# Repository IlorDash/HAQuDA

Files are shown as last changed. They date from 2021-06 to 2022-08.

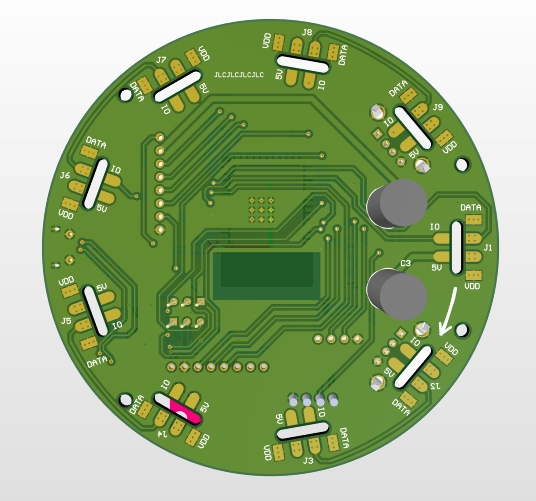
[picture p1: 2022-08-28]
Scheme/HAQuDA_Schematic/HAQuDA_Schematic_Bottom_Photo.jpg

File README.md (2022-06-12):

# HAQuDA
Home Air Quality Display And so on

Repository for project HAQuDA - table lamp that displays data of environmental parameters: air quality, temperature and humidity, by color of LEDs

Software is developed with VisualGDB

Article about (ru)
https://habr.com/ru/post/647117/

Assembly

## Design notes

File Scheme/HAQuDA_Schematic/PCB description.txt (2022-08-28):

Rounded rectangle slots (2.2 x 10.2 mm) around the board circle must be NON-PLATED. I placed in archive photos of each layers, how PCB must looks like

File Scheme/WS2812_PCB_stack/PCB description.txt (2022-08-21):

PCB is a panel of 6 PCBs (15mm x 96mm) similar design. I'd like it to be V-cut between each PCB. Single PCB outline is presented in layer - Mechanical 1. In each single PCB lengths between traces to outline are equal to 0.4mm, that fit to V-cut clearance.

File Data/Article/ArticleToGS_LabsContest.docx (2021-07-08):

# ОКВоДи: Отображатель Качества Воздуха Дома и так далее

# Оглавление

1. Сокращения
2. Описание
3. Актуальность
4. Устройство ОКВоДи
5. Основные функции
6. Прототип
7. Архитектура устройства
8. Технические характеристики

# Сокращения

PM 1.0, 2.5, 10 - particulate matter (взвешенные твердые микрочастицы размером <1 мкм, <2.5 мкм и <10 мкм соответственно. Примеры: пыль, вирусы и пыльца)
TVOC - total volatile organic compounds (общее количество летучих органических соединений. Примеры: сигаретный дым, бытовые и строительные аэрозоли, краски)
ppb - parts per billion (миллиардная доля, 1 ppb = 1 мм³/м³ - объемная доля или 1 ppb = 1 мкг/кг – массовая доля)
ppm – parts per million (миллионная доля, 1% = 10 000 ppm)
ОКВоДи – Отображатель Качества Воздуха Дома и так далее
HAQuDA – Home Air Quality Display And so on

# Описание

ОКВоДи – это настольная лампа, которая отображает данные о параметрах окружающей среды: качестве воздуха, температуре и влажности, при помощи цвета свечения. Если параметр в норме, то он зеленый, а если завышен или занижен, то красный или синий соответственно. У лампы есть несколько режимов отображения: стандартный, мульти, ночной, режим светильника.

# Актуальность

Основная идея устройства заключается в простоте передачи информации о состоянии дома человеку. Существующие модели датчиков качества воздуха передают информацию понятную специалистам, но специфичную для простых пользователей, например единица измерения CO2 – PPM, а количество летучей органики (формальдегиды, ацетон, этанол и т.д.) измеряется в микрограммах на кубический метр. ОКВоДи позволяет моментально и понятно отображать информацию о качестве воздуха, за счет ее отображения цветом: от зеленого – качество воздуха хорошее, до красного - когда уже пора проветрить помещения. В этом устройстве заложен принцип “преаттентивности” (от англ. pre-attention) - показывать тот объем информации, который необходим для принятия решения, что позволит человеку быстрее обрабатывать информации, не фокусируя на ней внимание. Этот принцип уже протестирован на устройстве, которое сделал мой брат: ОПЭДИ (https://habr.com/ru/post/523988/) и оно получило одобрение сообщества.

# Устройство ОКВоДи

Отображатель качества воздуха дома и так далее представляет собой лампу цилиндрической формы (90x130мм) состоящую из двух частей: матовая полупрозрачная белая верхняя часть и основание из непрозрачного пластика. Внутри верхней части на цилиндре закреплены адресные светодиоды WS2812B, в количестве 12x9 штук. Труба вставляется в плату и закрепляется в ней. На плате расположены ESP-32 mini и следующие датчики: датчик влажности и температуры – DHT-11 (https://www.mouser.com/datasheet/2/758/DHT11-Technical-Data-Sheet-Translated-Version-1143054.pdf), датчик летучих органических соединений и датчик угарного газа – CCS811 (https://cdn.sparkfun.com/assets/learn_tutorials/1/4/3/CCS811_Datasheet-DS000459.pdf), датчик озона - ZE25-O3 (https://www.winsen-sensor.com/sensors/o3-gas-sensor/ze25-o3.html). Под платой располагается датчик взвешенных частиц - ZH03B (https://www.winsen-sensor.com/sensors/dust-sensor/zh3b.html). Отладочный комплект Silicon Labs будет подключаться снаружи по протоколу UART. Для изменения яркости лампы в зависимости от яркости окружающего света, установлены датчики освещения. В верхней крышке расположены сенсорные кнопки, чтобы отслеживать касания и менять режим отображения, и датчик расстояния, для ручного управления яркостью. Также на плате располагается два USB-A выхода для зарядки устройств и один USB-Micro вход питания. В комплектации к лампе идет адаптер питания 5В 2А с выходом на USB-A и кабель USB-A – USB-Micro. Для работы требуется подключение в сеть электропитания, по этой причине в сети ZigBee ОКВоДи будет выступать в роли координатора. Режим работы у лампы только рабочий.

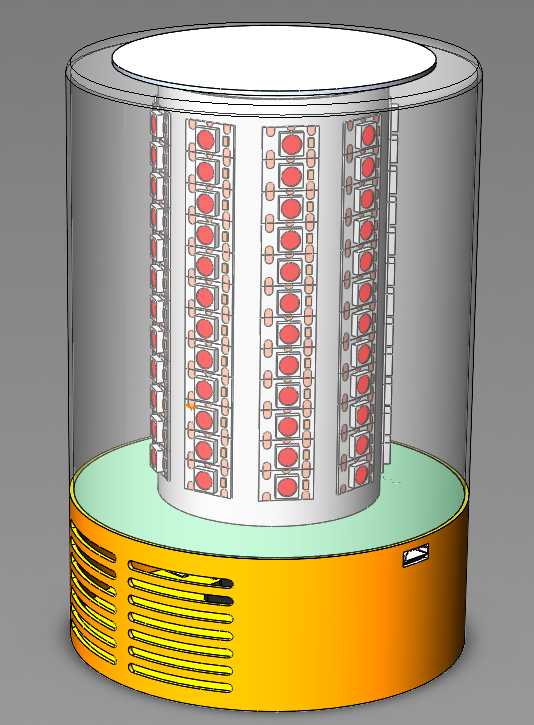
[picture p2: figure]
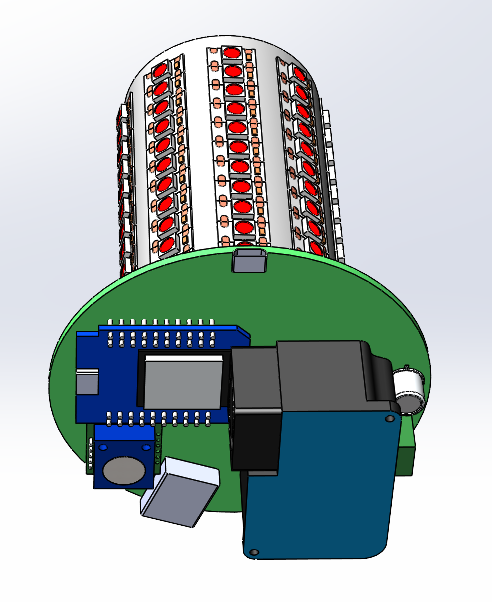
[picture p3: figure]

Расположение компонентов

Модель лампы

# Основные функции

ОКВоДи умеет отображать следующие параметры микроклимата дома:

- Летучие органические соединения (TVOC) – измеряется в частицах на миллиард [ppb]
- Количество озона (O3) – измеряется в частицах на миллиард [ppb]
- Твердые частицы PM1.0, PM2.5, PM10 (Dust) – измеряется в микрограммах на метр кубический [мкг/м3]
- Углекислый газ (CO2) - измеряется в частицах на миллион [ppm]
- Температура – измеряется в градусах Цельсия [°C]
- Влажность – измеряется в процентах [%]
- Общее качество воздуха (TotalAirQuality) – рассчитывается на основе всех предыдущих показателей

Выбор именно этих показателей качества воздуха связан с тем, что они оказывают основное долговременное воздействие на человека. Исследования, доказывающие влияние качества воздуха на состояние человека и международные нормы количества этих показателей в помещениях:

1. Ioannis Manisalidis, Elisavet Stavropoulou, Agathangelos Stavropoulos and Eugenia Bezirtzoglou Environmental and Health Impacts of Air Pollution: A Review / Front. Public Health, 20 February 2020 - https://www.frontiersin.org/articles/10.3389/fpubh.2020.00014/full
2. Vinh Van Tran, Duckshin Park, and Young-Chul Lee Indoor Air Pollution, Related Human Diseases, and Recent Trends in the Control and Improvement of Indoor Air Quality / Int J Environ Res Public Health. 2020 Apr; 17(8) -https://www.ncbi.nlm.nih.gov/pmc/articles/PMC7215772/
3. Мансуров Р.Ш. Гурин М.А. Рубель Е.В. Влияние концентрации углекислого газа на организм человека / Universum: технические науки 2017 № 8 (41) - https://7universum.com/ru/tech/archive/item/5045
4. Губернский Ю.Д. Калинина Н.В. Гапонова Е.Б. Банин И.М. Обоснование допустимого уровня содержания диоксида углерода в воздухе помещений жилых и общественных зданий / ГИГИЕНА И САНИТАРИЯ Том 93, № 6 (2014) https://elibrary.ru/item.asp?id=22804038
5. Occupational Safety and Health Administration OSHA and Ozone - https://ozonesolutions.com/blog/osha-and-ozone/

Режимы отображения:

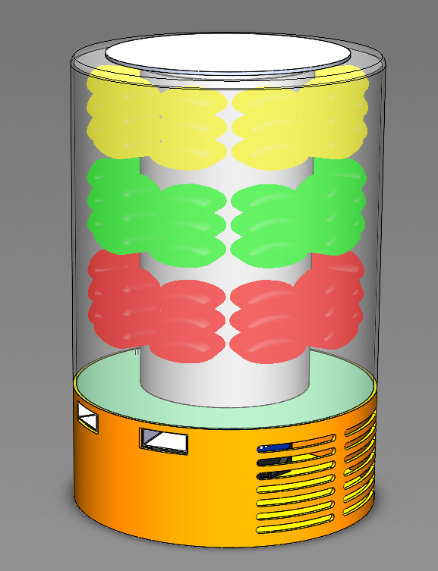
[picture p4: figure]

- Основной (Standard-mode) – все светодиоды задействованы для одного конкретного параметра
- Мульти-режим (Multi-mode) – светодиоды делятся на три секции и отображают три параметра, выбранные пользователем
- Ночной (Night-mode) – три вертикальные линии светодиодов выделяются под отображение одного параметра, заданного пользователем, остальные выполняют роль подсветки-ночника и отображают время. Пользователь вводит временной диапазон, например от времени засыпания, до будильника, по умолчанию установлен с 21.00 до 09.00. Каждый час загорается следующий светодиод подсветки, таким образом яркость ночника увеличивается с наступлением утра. Отображение времени тоже преаттентивно: по уровню заполнения подсветки можно примерно определить оставшееся время для сна. В итоге получается progress bar времени вашего сна.

Пример мульти-режима, выключенные светодиоды не отображены

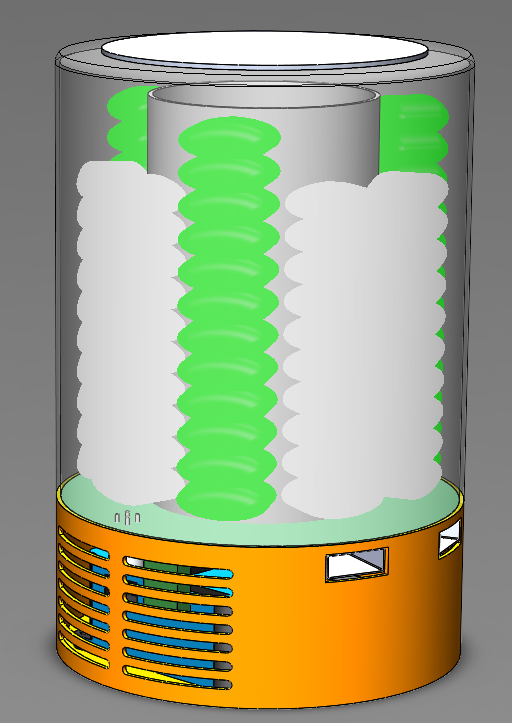
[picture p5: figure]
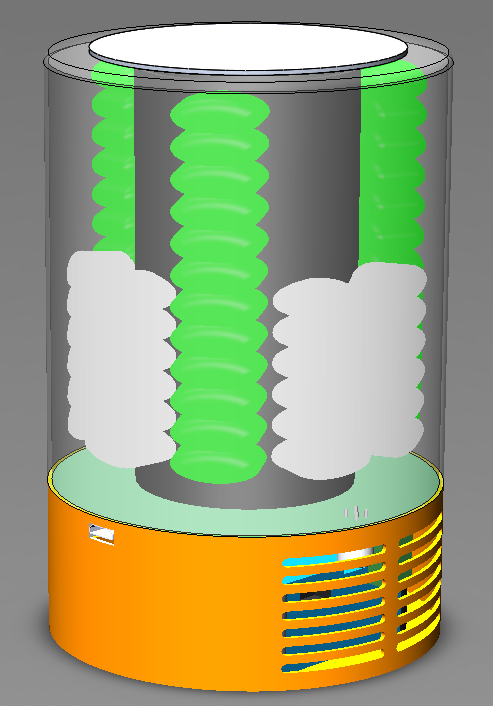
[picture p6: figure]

Пример ночного режима с установленным по умолчанию диапазоном времени. Зеленые – полосы отображения, например качества воздуха, белые - подсветка. Первая картинка соответствует 3 часам ночи, вторая – 7 часам утра

Так как это лампа, у нее есть одноцветная подсветка любым цветом (Lamp-mode), и несколько эффектов (Effect-mode): горящее пламя, огоньки, радуга. Пользователь может управлять автоматической регулировкой яркости, она происходит благодаря датчикам освещенности. Также менять яркость можно с помощью дальномера: поднесите руку над ОКВоДи и поднимая руку вы будете увеличивать яркость и наоборот. Для полного выключения освещения лампы достаточно хлопнуть по верхней крышке, в которой установлен сенсорный датчик.

Для удаленного управление лампой на модуле ESP-32 будет развернут веб-сервер, который позволит менять режимы отображения параметров, включать одноцветную подсветку и эффекты. На веб-сервере будут отображаться текущие показатели микроклимата дома, графики показателей за несколько дней.

ОКВоДи будет интегрирована с Яндекс Алисой для голосового управления. С помощью навыка “Домовенок Кузя” Алиса будет отправлять HTTP запросы на веб-сервер ESP-32 и, например, включать ночной режим или выключать лампу. Выбор Алисы обусловлен ее популярностью, поддержкой русского языка и простотой ее навыка. Так же для поддержки iOS устройств будет реализована интеграция с Apple HomeKit посредством ESP HomeKit SDK.

В сопряжении с другими устройствами умного дома, ОКВоДи сможет работать и как информационный модуль, и как управляющий. ОКВоДи будет получать информацию от других датчиков и так же отображать ее цветом светодиодов. Например, датчик энергопотребления будет сообщать свои данные лампе, а та в свою очередь будет отображать их, для контроля за энергопотреблением в реальном времени. Это можно будет применить и в сценариях, подобным, "Выход из дома", то есть показать, что основная часть электроприборов отключена. Другой вариант - отображать усредненные параметры качества воздуха с нескольких датчиков, расположенных в доме. В случае ухудшения качества воздуха, например увеличении концентрации CO2, ОКВоДи сможет подать команду на открытие окна или включения бризера. Общение между модулями будет реализовано с помощью Wi-Fi или ZigBee, в зависимости от внешнего устройства. Для отображения данных других датчиков необходимо будет добавить соответствующее значение атрибуту Description (0x001C) кластеров Display param 1-3.

# Прототип

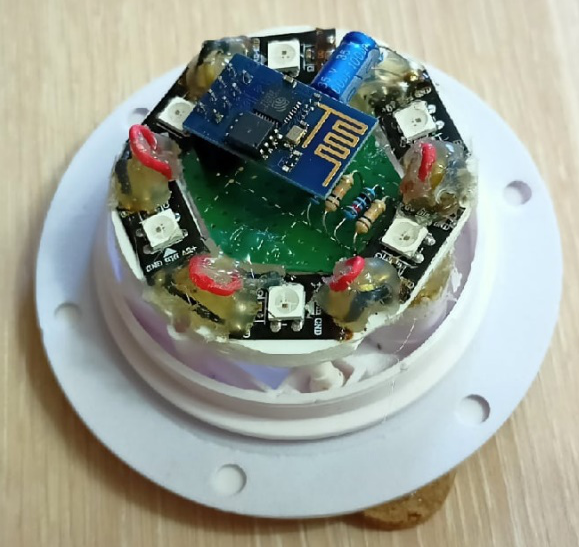
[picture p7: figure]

Уже имеется прототип ОКВоДи – умная лампа Ambient Orb, выполненная на WiFi модуле ESP-8266 и адресных светодиодах. Она умеет отображать температуру или влажность в помещении цветом светодиодов.

Плата Ambient Orb

Однако из-за небольшого количества светодиодов, на лампе нельзя реализовать много режимов отображения. Также отображение температуры в рамках одной комнаты оказалось не столь необходимым, так как человек сразу ощущает, что в комнате некомфортная температура, но с качеством воздуха все обстоит немного иначе, комнатный воздух – тихий убийца: вы не сразу почувствуете, что он ухудшился, однако последствия этого могут быть очень неприятными, от головной боли до инсульта, сердечно-сосудистых заболеваний, и даже рака легких. Поэтому я решил доработать AmbientOrb, сделать его более функциональным, полезным и совместить с другими устройствами умного дома. Так и родилась идея ОКВоДи!

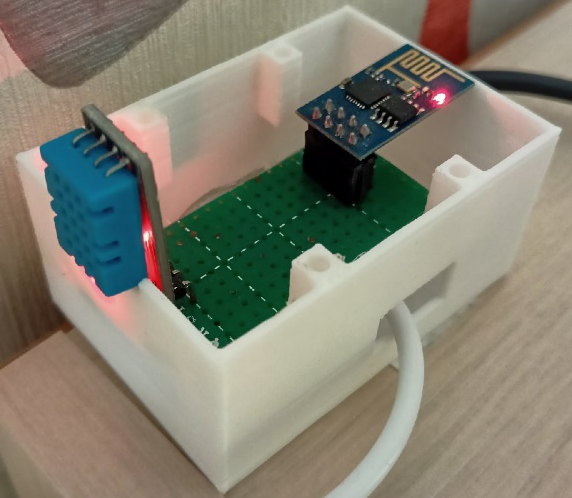
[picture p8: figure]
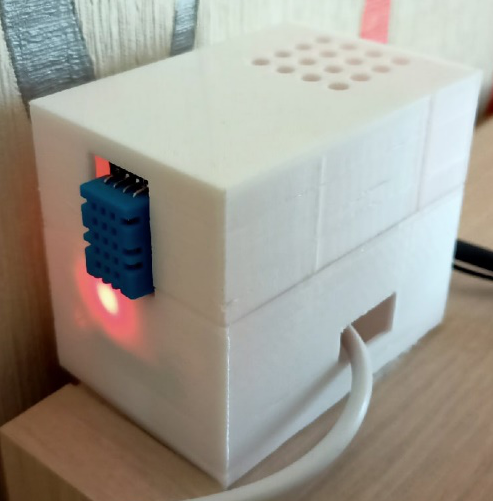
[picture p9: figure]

Для измерения влажности и температуры собран внешний датчик на DHT-11 и ESP-8266, который отправляет данные на Ambient Orb для их последующего отображения.

Датчик температуры и его плата

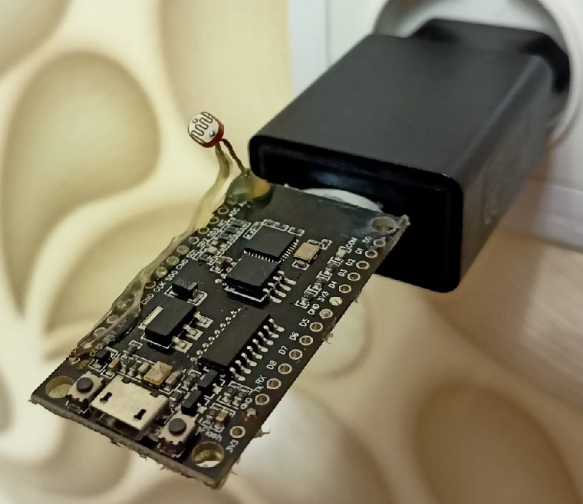
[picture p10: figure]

Яркость Ambient Orb может менять автоматически, в зависимости от внешнего освещения с помощью датчика света на фоторезисторе и платформе Node MCU.

Датчик света

Все эти устройства подключены к домашней сети Wi-Fi, датчики отправляют свои данные на Ambient Orb через HTTP запросы. Питаются все устройства от 5В и у всех есть для этого USB-A выходы. На Ambient Orb развернут веб-сервер, на котором можно настроить параметры лампы. Для голосового управления я подключил к Ambient Orb голосового помощника от Google через сервис IFTTT, который отправлял HTTP запросы на веб сервер. Видео демонстрацию работы Ambient Orb доступно на Яндекс Диске https://disk.yandex.ru/i/SMD_wlGtvY4n-g.

# Архитектура устройства

Endpoint 1. HAQuDa-general
Cluster | Description
Basic cluster 0x0000 (0) | Attributes ID | Name | Default value
| 0x0000 (0) | ZCL version | 2
| 0x0003 (3) | HW version | 0x01
| 0x0004 (4) | Manufacture name | IlorDash
| 0x0005 (5) | Model identifier | HAQuDA
| 0x0006 (6) | Date Code | 2021.6.09
| 0x0007 (7) | Power source | 0x04
Identify cluster 0x0003 (3) | Attributes ID | Name | Default value
| 0x0000 (0) | Identify Time | 0x0000
On/Off cluster 0x0006 (6) | Attributes ID | Name | Default value
| 0x0000 (0) | OnOff | 1
Mode 0xfc01 (64512) (CUSTOM) | Attributes ID | Name | Default value
| 0x001C | Description | Standard (Other modes: Multi, Night, Lamp, Effects)

Endpoint 2. Standard-mode
Cluster | Description
Basic cluster 0x0000 (0) | Attributes ID | Name | Default value
| 0x0000 (0) | ZCL version | 2
| 0x0003 (3) | HW version | 0x01
| 0x0004 (4) | Manufacture name | IlorDash
| 0x0005 (5) | Model identifier | HAQuDA
| 0x0006 (6) | Date Code | 2021.6.09
| 0x0007 (7) | Power source | 0x04
Identify cluster 0x0003 (3) | Attributes ID | Name | Default value
| 0x0000 (0) | Identify Time | 0x0000
Level Control 0x0008 (8) | Attributes ID | Name | Default value
| 0x0000 | CurrentLevel | -
| 0x0001 | RemainingTime | 0x0000
| 0x0010 | OnOffTransitionTime | 0x0000
| 0x0011 | OnLevel | 0xff
Display param 1 0xfc01 (64513) (CUSTOM) | Attributes ID | Name | Default value
| 0x001C | Description | TotalAirQuality (Other parameters to display: TVOC, O3, Dust, CO2, Temp, Humid)

Endpoint 3. Multi-mode
Cluster | Description
Basic cluster 0x0000 (0) | Attributes ID | Name | Default value
| 0x0000 (0) | ZCL version | 2
| 0x0003 (3) | HW version | 0x01
| 0x0004 (4) | Manufacture name | IlorDash
| 0x0005 (5) | Model identifier | HAQuDA
| 0x0006 (6) | Date Code | 2021.6.09
| 0x0007 (7) | Power source | 0x04
Identify cluster 0x0003 (3) | Attributes ID | Name | Default value
| 0x0000 (0) | Identify Time | 0x0000
Level Control 0x0008 (8) | Attributes ID | Name | Default value
| 0x0000 | CurrentLevel | -
| 0x0001 | RemainingTime | 0x0000
| 0x0010 | OnOffTransitionTime | 0x0000
| 0x0011 | OnLevel | 0xff
Display param 1 0xfc01 (64513) (CUSTOM) | Attributes ID | Name | Default value
| 0x001C | Description | TotalAirQuality (Other parameters to display: TVOC, O3, Dust, CO2, Temp, Humid)
Display param 2 0xfc02 (64514) (CUSTOM) | Attributes ID | Name | Default value
| 0x001C | Description | Temp (Other parameters to display: TVOC, O3, Dust, CO2, TotalAirQuality, Humid)
Display param 3 0xfc03 (64515) (CUSTOM) | Attributes ID | Name | Default value
| 0x001C | Description | Humid (Other parameters to display: TVOC, O3, Dust, CO2, TotalAirQuality, Temp)

Endpoint 4. Night-mode
Cluster | Description
Basic cluster 0x0000 (0) | Attributes ID | Name | Default value
| 0x0000 (0) | ZCL version | 2
| 0x0003 (3) | HW version | 0x01
| 0x0004 (4) | Manufacture name | IlorDash
| 0x0005 (5) | Model identifier | HAQuDA
| 0x0006 (6) | Date Code | 2021.6.09
| 0x0007 (7) | Power source | 0x04
Identify cluster 0x0003 (3) | Attributes ID | Name | Default value
| 0x0000 (0) | Identify Time | 0x0000
On/Off cluster 0x0006 (6) | Attributes ID | Name | Default value
| 0x0000 (0) | OnOff | 1
Level Control 0x0008 (8) | Attributes ID | Name | Default value
| 0x0000 | CurrentLevel | -
| 0x0001 | RemainingTime | 0x0000
| 0x0010 | OnOffTransitionTime | 0x0000
| 0x0011 | OnLevel | 0xff
Display param 1 0xfc01 (64513) (CUSTOM) | Attributes ID | Name | Default value
| 0x001C | Description | TotalAirQuality (Other parameters to display: TVOC, O3, Dust, CO2, Temp, Humid)
Time bounds 0xfc04 (64516) (CUSTOM) | Attributes ID | Name | Default value
| 0x0000 | UpperBound (in minutes from midnight) | 0x021C (09:00 AM)
| 0x0001 | LowerBound (in minutes from midnight) | 0x04EC (09:00 PM)
| 0x0002 | TimeZone | 0x00000000

Time bounds Attribute Set
Identifier | Name | Type | Range | Acces | Default | | M/O
0x0000 | UpperBound (in minutes from midnight) | uint16 | 0x0000 – 0x05A0 | Read Write | 0x021C (09:00 AM) | | M
0x0001 | LowerBound (in minutes from midnight) | uint16 | 0x0000 – 0x05A0 | Read Write | 0x04EC (09:00 PM) | | M
0x0002 | TimeZone | int32 | -86400 - +86400 | Read Write | 0x00000000 | | M

Сервер принимает только команды на чтение/запись данных атрибутов

Endpoint 5. Lamp-mode
Cluster | Description
Basic cluster 0x0000 (0) | Attributes ID | Name | Default value
| 0x0000 (0) | ZCL version | 2
| 0x0003 (3) | HW version | 0x01
| 0x0004 (4) | Manufacture name | IlorDash
| 0x0005 (5) | Model identifier | HAQuDA
| 0x0006 (6) | Date Code | 2021.6.09
| 0x0007 (7) | Power source | 0x04
Identify cluster 0x0003 (3) | Attributes ID | Name | Default value
| 0x0000 (0) | Identify Time | 0x0000
Level Control 0x0008 (8) | Attributes ID | Name | Default value
| 0x0000 | CurrentLevel | -
| 0x0001 | RemainingTime | 0x0000
| 0x0010 | OnOffTransitionTime | 0x0000
| 0x0011 | OnLevel | 0xff
Color Control 0x0300 (768) | Attributes ID | Name | Default value
| 0x0000 | CurrentHue | 0x00
| 0x0001 | CurrentSaturation | 0x00
| 0x0008 | ColorMode | 0x00
| 0x4001 | EnhancedColorMode | 0x00
| 0x400a | ColorCapabilities | 0x0000

Endpoint 6. Effects-mode
Cluster | Description
Basic cluster 0x0000 (0) | Attributes ID | Name | Default value
| 0x0000 (0) | ZCL version | 2
| 0x0003 (3) | HW version | 0x01
| 0x0004 (4) | Manufacture name | IlorDash
| 0x0005 (5) | Model identifier | HAQuDA
| 0x0006 (6) | Date Code | 2021.6.09
| 0x0007 (7) | Power source | 0x04
Identify cluster 0x0003 (3) | Attributes ID | Name | Default value
| 0x0000 (0) | Identify Time | 0x0000
Level Control 0x0008 (8) | Attributes ID | Name | Default value
| 0x0000 | CurrentLevel | -
| 0x0001 | RemainingTime | 0x0000
| 0x0010 | OnOffTransitionTime | 0x0000
| 0x0011 | OnLevel | 0xff
Effect 0xfc05 (64517) (CUSTOM) | Attributes ID | Name | Default value
| 0x001C | Description | Flame (Other parameters to display: Lights, Rainbow)

# Технические характеристики

## Связь

- Wi-Fi (802.11): 2.4 GHz (up to 150 Mbps)
- ZigBee

## Общие характеристики

- Управление: систему Умный дом DREHOME&TV, через веб-сервер
- Тип подключения: ZigBee, Wi-Fi

## Питание

- Источник питания: блок питания в комплекте
- Параметры входа: 220V - 50Hz
- Параметры выхода: 5V - 2A

## Измерения

- Температура: 0 – 50 ℃ ±5 %
- Влажность: 20 – 90 %RH ± 2%
- Летучие органические соединения: 0 – 1187 ppb
- Количество озона: 0 – 10 ppm ±0.01ppm
- Твердые частицы PM1.0, PM2.5, PM10: 0~100μg/m3: ±15μg/m3 101~1000μg/m3: ±15%
- Углекислый газ: 400 – 8192 ppm

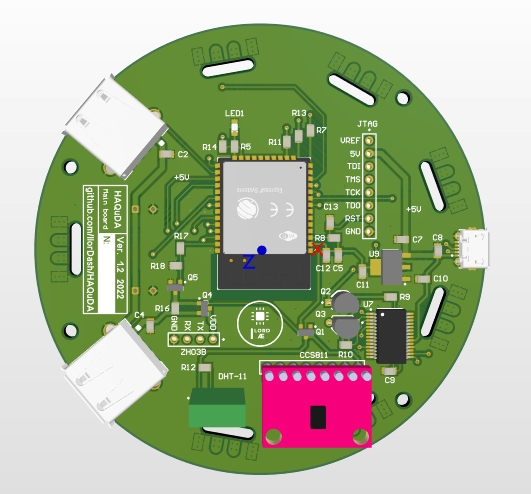
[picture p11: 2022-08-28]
Scheme/HAQuDA_Schematic/HAQuDA_Schematic_Top_Photo.jpg

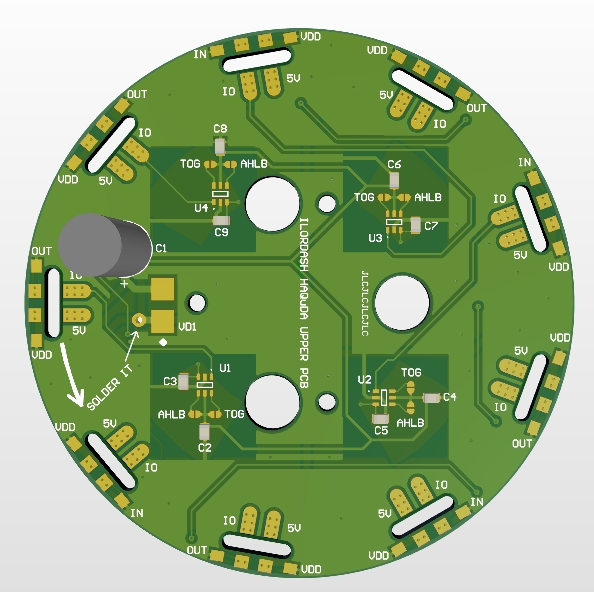
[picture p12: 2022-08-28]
Scheme/HAQuDA_upper_PCB/HAQuDA_upper_PCB_Bottom_Photo.jpg

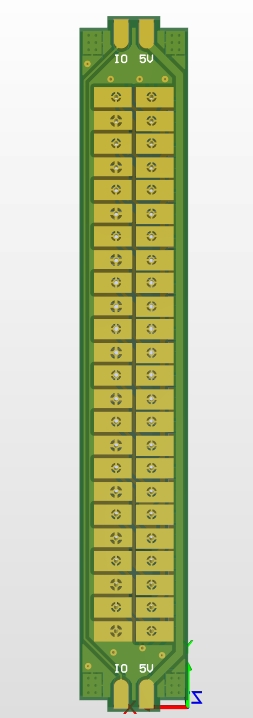
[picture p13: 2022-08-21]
Scheme/WS2812_PCB_stack/WS2812_PCB_stack_Bottom_Photo.jpg

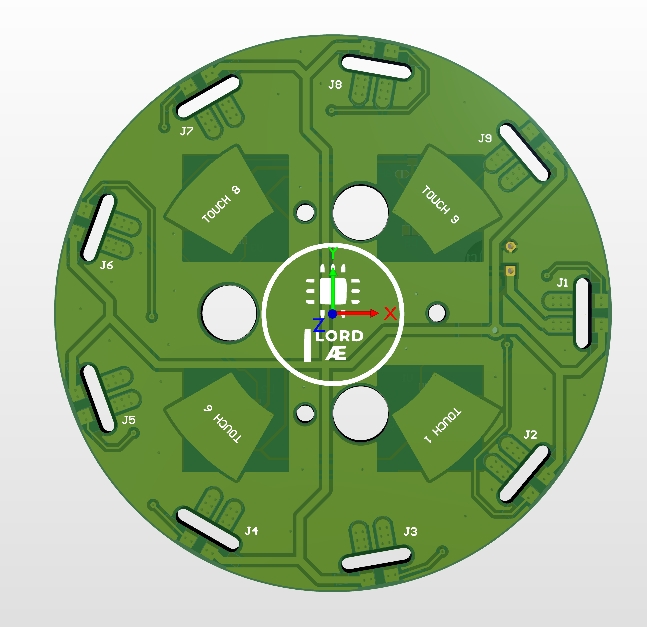
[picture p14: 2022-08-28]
Scheme/HAQuDA_upper_PCB/Project Outputs for HAQuDA_upper_PCB/HAQuDA_upper_PCB_Top_Photo.jpg

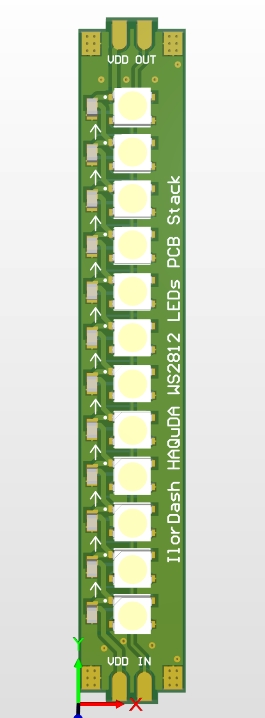
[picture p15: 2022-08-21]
Scheme/WS2812_PCB_stack/WS2812_PCB_stack_Top_Photo.jpg

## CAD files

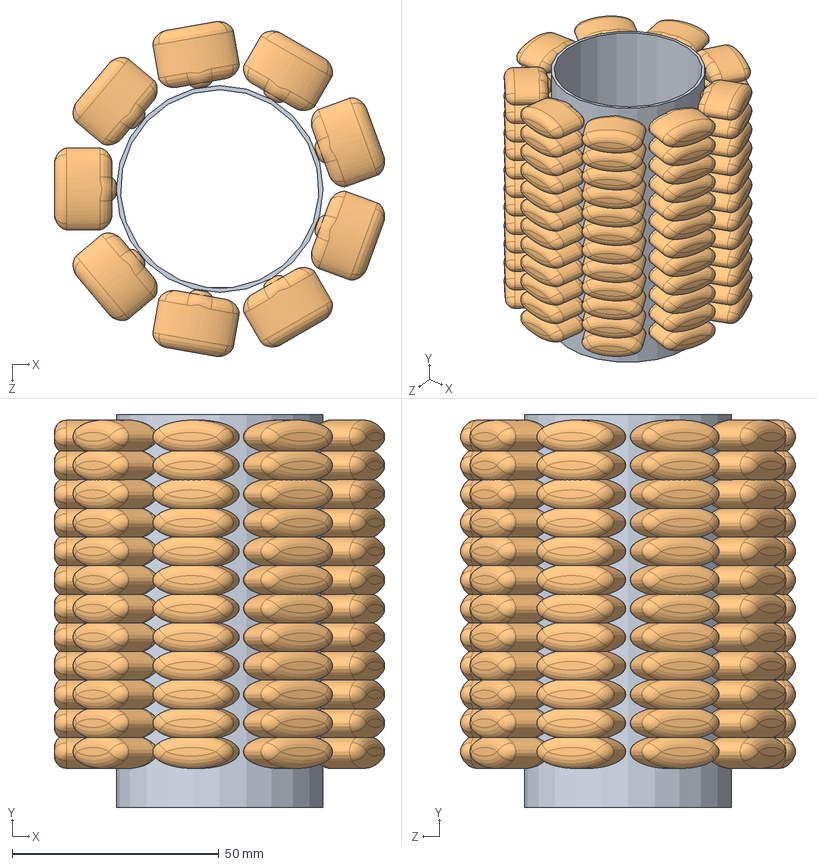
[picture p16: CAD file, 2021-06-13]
Models/Demo/Demo_LampTubeLed_Night_1.SLDASM
79.9 x 95.0 x 81.0 mm
lampTube
DemoLed x 108

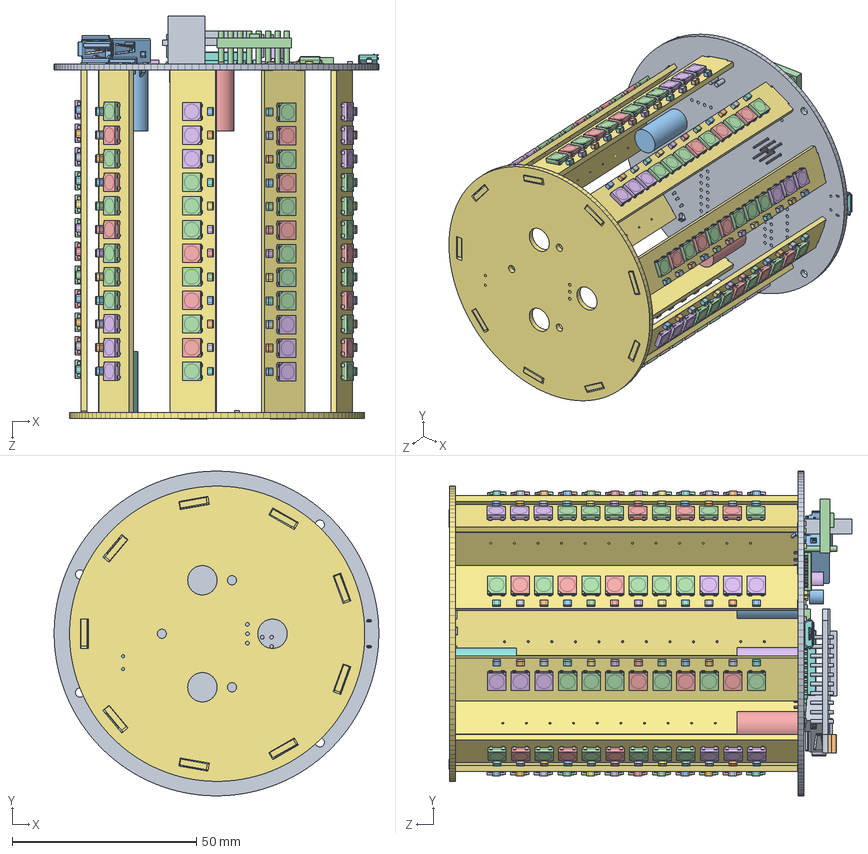
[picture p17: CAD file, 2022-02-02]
Models/Details/HAQuDA_PCB_Assembly.SLDASM
88.0 x 88.0 x 109.2 mm
Board
R18
R17
R16
R15
Q5
Q4
Q1
ESP-32_mini
USB-Micro_® ã¬®«ç ¨î
C-292303-1
R7
R14
R13
R12
Logo
Assem1
base
cover
marking x 2
base_2
C13
C12
CCS811
C5
Q3
Board_2 x 2
Board_3 x 6
Extruded x 4
Extruded_2 x 2
Q2
U9
C11
C10
R11
R10
DHT-11_without_case
R9
Leader x 28
C8
C9
C7
R1
R6
R4
R3
R2
R8
R5
C-292303-1_2
C4
C3
C2
C6
C1
Board_4 x 9
C12_2 x 9
C11_2 x 9
C10_2 x 9
C9_2 x 9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

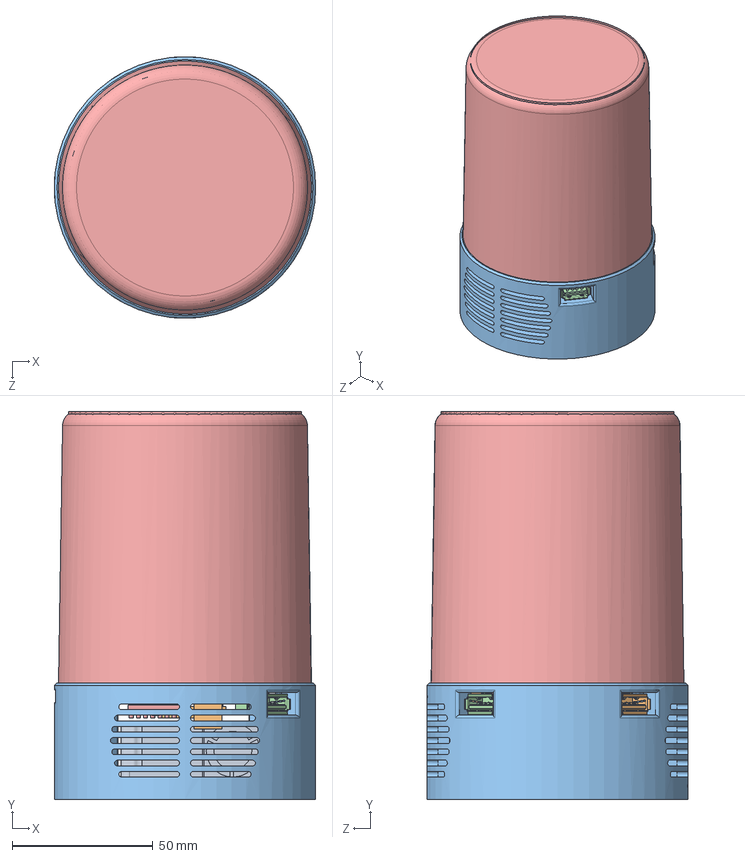
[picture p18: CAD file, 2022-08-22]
Models/HAQuDA_Assembly.SLDASM
93.0 x 138.0 x 93.0 mm
ZH03B_DustModule
Board
R18
R17
R16
R15
Q5
Q4
Q1
ESP-32_mini
USB-Micro_® ã¬®«ç ¨î
C-292303-1
R7
R14
R13
R12
Logo
Assem1
base
cover
marking x 2
base_2
C13
C12
CCS811
C5
Q3
Board_2 x 2
Board_3 x 6
Extruded x 4
Extruded_2 x 2
Q2
U9
C11
C10
R11
R10
DHT-11_without_case
R9
Leader x 28
C8
C9
C7
R1
R6
R4
R3
R2
R8
R5
C-292303-1_2
C4
C3
C2
C6
C1
Board_4 x 9
C12_2 x 9
C11_2 x 9
C10_2 x 9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

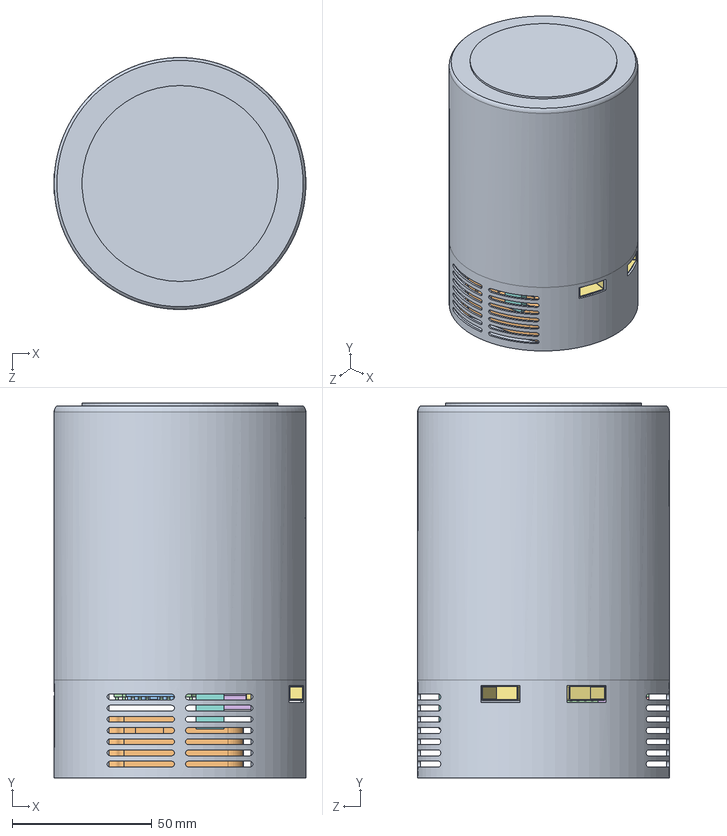
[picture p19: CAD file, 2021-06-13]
Models/Demo/Demo_HAQuDA_Assembly_Multi.SLDASM
90.0 x 134.0 x 90.0 mm
Lamp
ZH03B_DustModule
PCB^Demo_HAQuDA_Assembly_Multi
ESP-32_mini_board^ESP-32_mini
USB-Micro x 2
ZE-25-O3_Sensor
USB-A x 2
DHT-11_without_case
lampTube
DemoLed x 81
CCS811

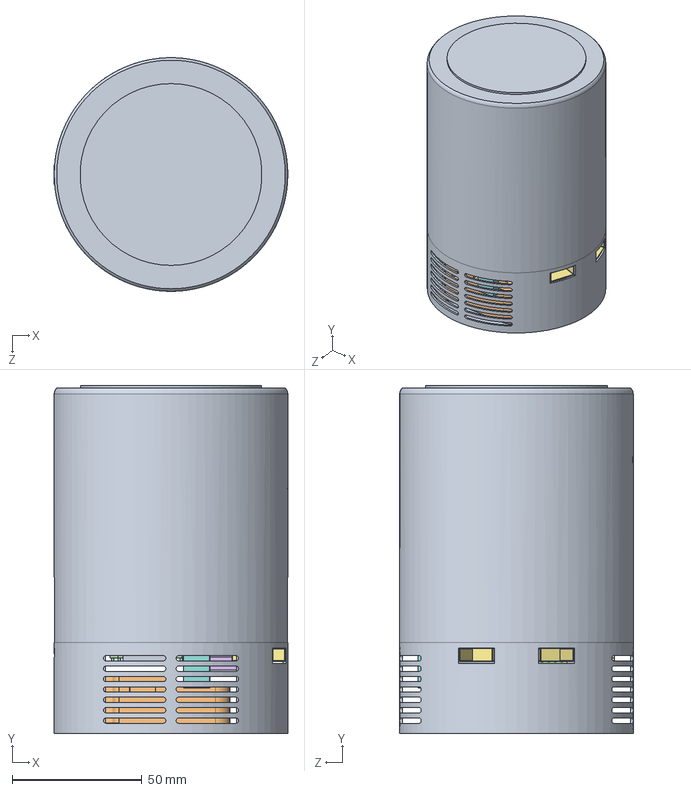
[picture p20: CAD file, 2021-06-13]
Models/Demo/Demo_HAQuDA_Assembly_Night_2.SLDASM
90.0 x 134.0 x 90.0 mm
Lamp
ZH03B_DustModule
PCB^Demo_HAQuDA_Assembly_Night_2
ESP-32_mini_board^ESP-32_mini
USB-Micro x 2
ZE-25-O3_Sensor
USB-A x 2
DHT-11_without_case
CCS811
lampTube
DemoLed x 108

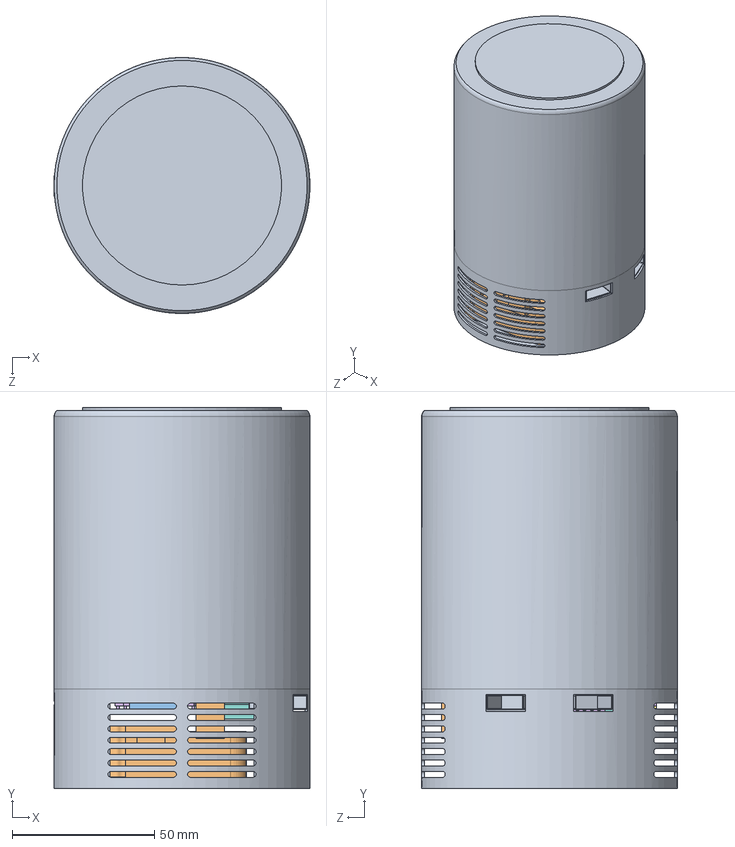
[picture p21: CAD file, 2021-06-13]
Models/Demo/Demo_HAQuDA_Assembly_Night_1.SLDASM
90.0 x 134.0 x 90.0 mm
Lamp
ZH03B_DustModule
PCB^Demo_HAQuDA_Assembly_Night_1
lampTube
DemoLed x 72
ESP-32_mini_board^ESP-32_mini
USB-Micro x 2
ZE-25-O3_Sensor
USB-A x 2
DHT-11_without_case
CCS811

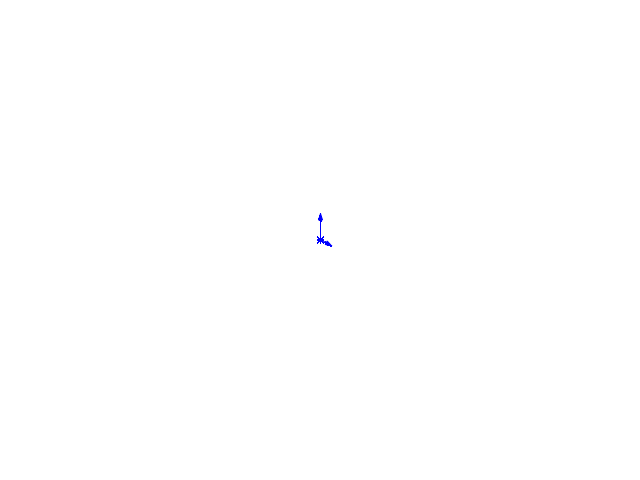
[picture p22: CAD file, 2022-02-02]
Models/Details/PCB_assembly_files/Free-Models_2.SLDASM
Board_3 x 3
Extruded x 2
Extruded_2

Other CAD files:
Models/Demo/Demo_LampTubeLed_Night_2.SLDASM
Models/Details/PCB_assembly_files/Imported_11.SLDASM
Models/Demo/Demo_LampTubeLed_Multi.SLDASM
Models/Details/PCB_assembly_files/J11.SLDASM
Models/Details/PCB_assembly_files/U8.SLDASM
Models/Details/PCB_assembly_files/Imported_12.SLDASM
Models/Details/PCB_assembly_files/Q2.SLDASM
Models/Details/PCB_assembly_files/Imported_18.SLDASM
Models/Details/PCB_assembly_files/U4_2.SLDASM
Models/Details/PCB_assembly_files/U7_2.SLDASM
Models/Details/PCB_assembly_files/Imported_7.SLDASM
Models/Body/Diffuser.SLDPRT
Models/Body/Lamp_cap_fastener.SLDPRT
Models/Body/Lamp_case.SLDPRT
Models/Demo/DemoLed.SLDPRT
Models/Details/MP-4_Gas_sensor.SLDPRT
Models/Details/PCB_assembly_files/1.SLDASM
Models/Details/PCB_assembly_files/1.SLDPRT
Models/Details/PCB_assembly_files/10.SLDPRT
Models/Details/PCB_assembly_files/1050170001.SLDPRT
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

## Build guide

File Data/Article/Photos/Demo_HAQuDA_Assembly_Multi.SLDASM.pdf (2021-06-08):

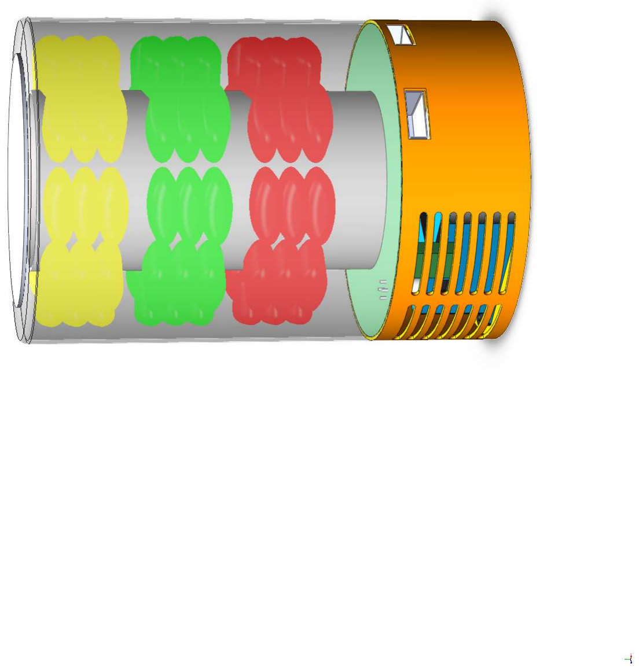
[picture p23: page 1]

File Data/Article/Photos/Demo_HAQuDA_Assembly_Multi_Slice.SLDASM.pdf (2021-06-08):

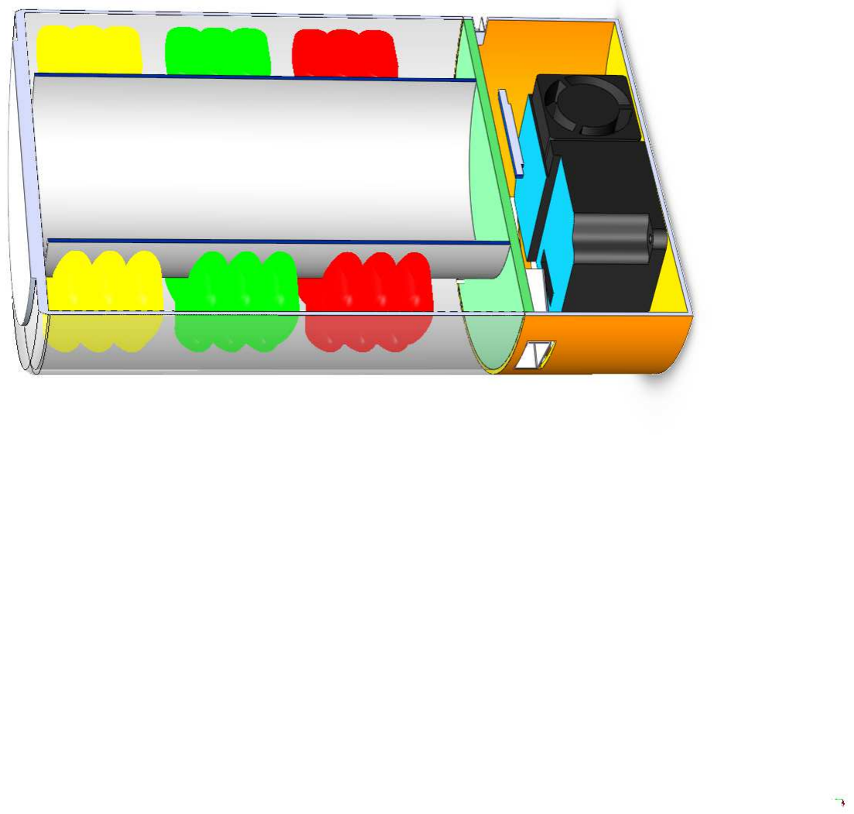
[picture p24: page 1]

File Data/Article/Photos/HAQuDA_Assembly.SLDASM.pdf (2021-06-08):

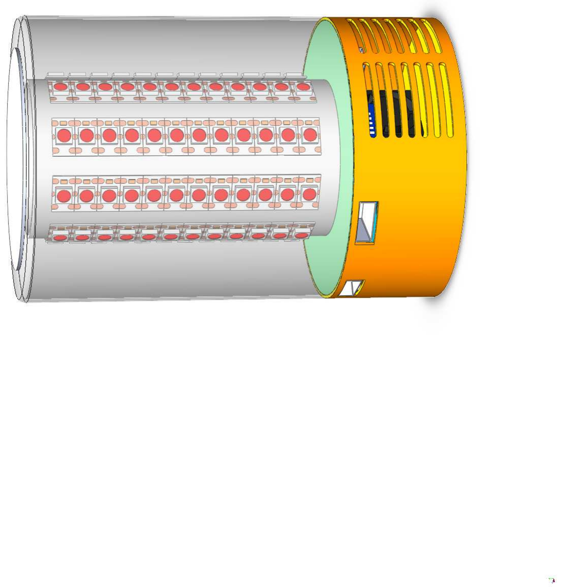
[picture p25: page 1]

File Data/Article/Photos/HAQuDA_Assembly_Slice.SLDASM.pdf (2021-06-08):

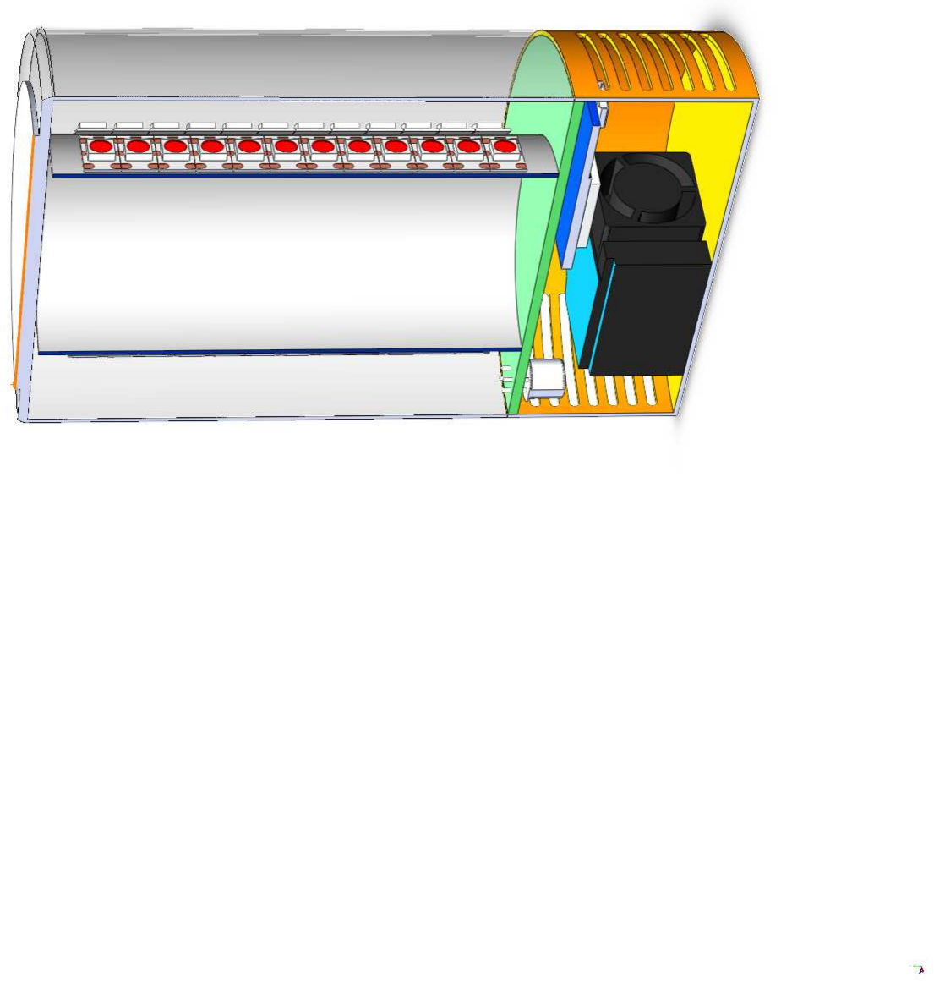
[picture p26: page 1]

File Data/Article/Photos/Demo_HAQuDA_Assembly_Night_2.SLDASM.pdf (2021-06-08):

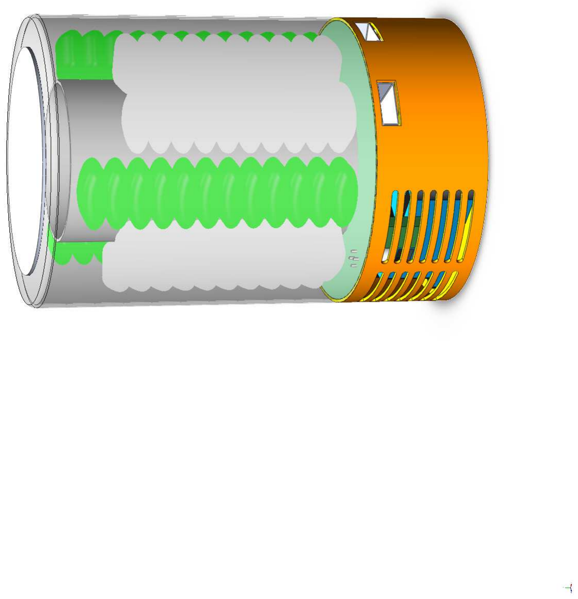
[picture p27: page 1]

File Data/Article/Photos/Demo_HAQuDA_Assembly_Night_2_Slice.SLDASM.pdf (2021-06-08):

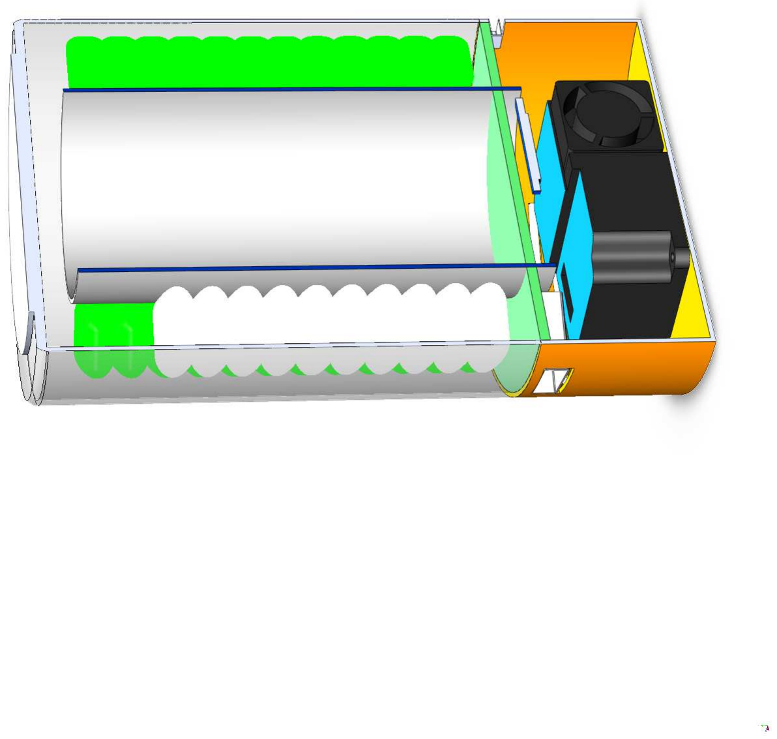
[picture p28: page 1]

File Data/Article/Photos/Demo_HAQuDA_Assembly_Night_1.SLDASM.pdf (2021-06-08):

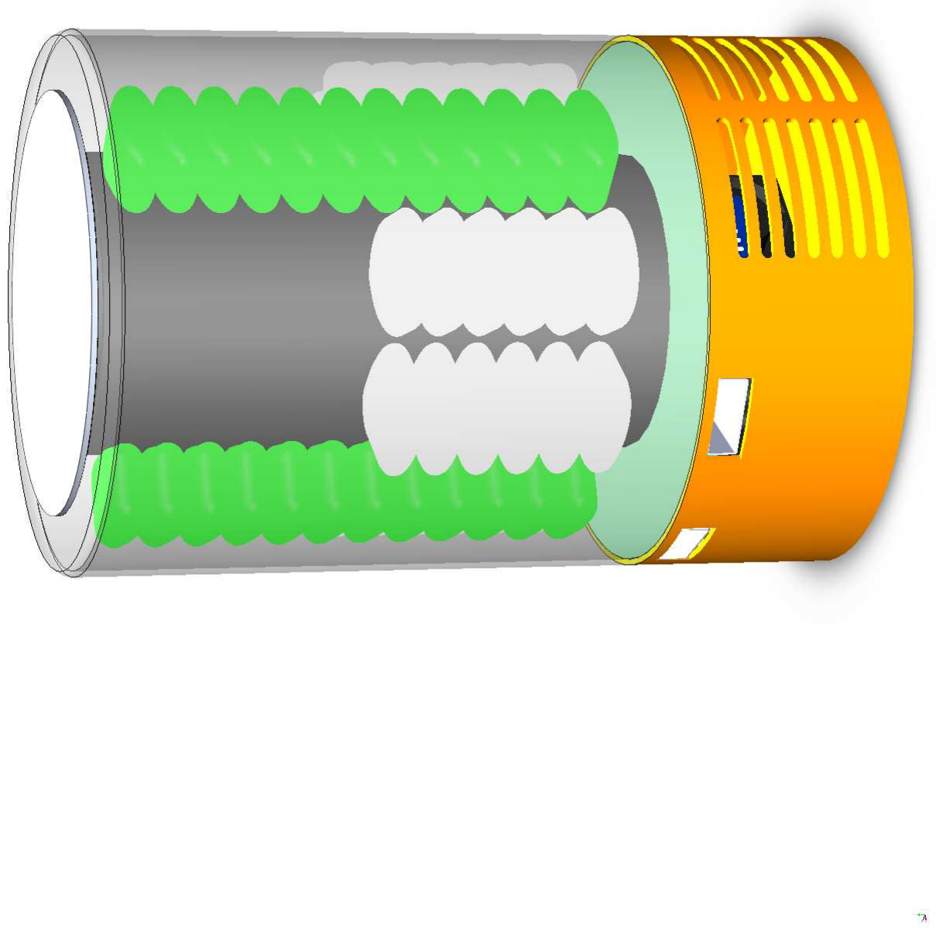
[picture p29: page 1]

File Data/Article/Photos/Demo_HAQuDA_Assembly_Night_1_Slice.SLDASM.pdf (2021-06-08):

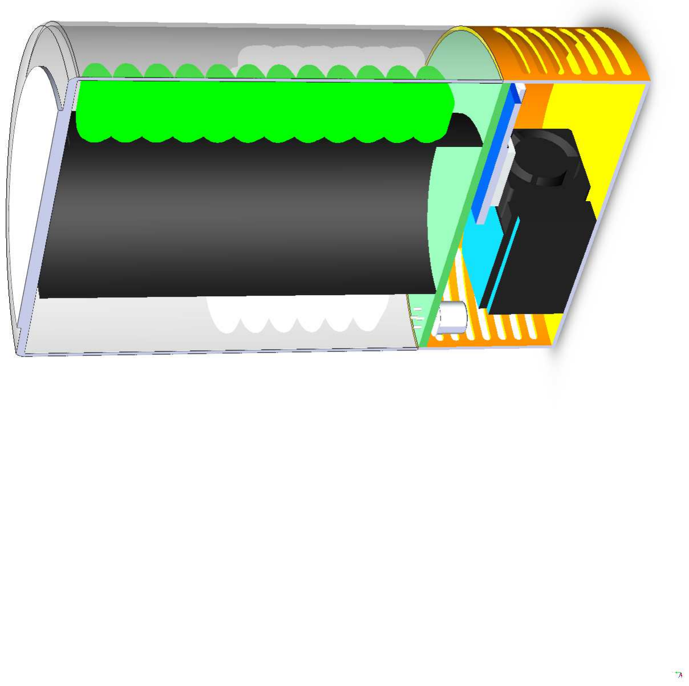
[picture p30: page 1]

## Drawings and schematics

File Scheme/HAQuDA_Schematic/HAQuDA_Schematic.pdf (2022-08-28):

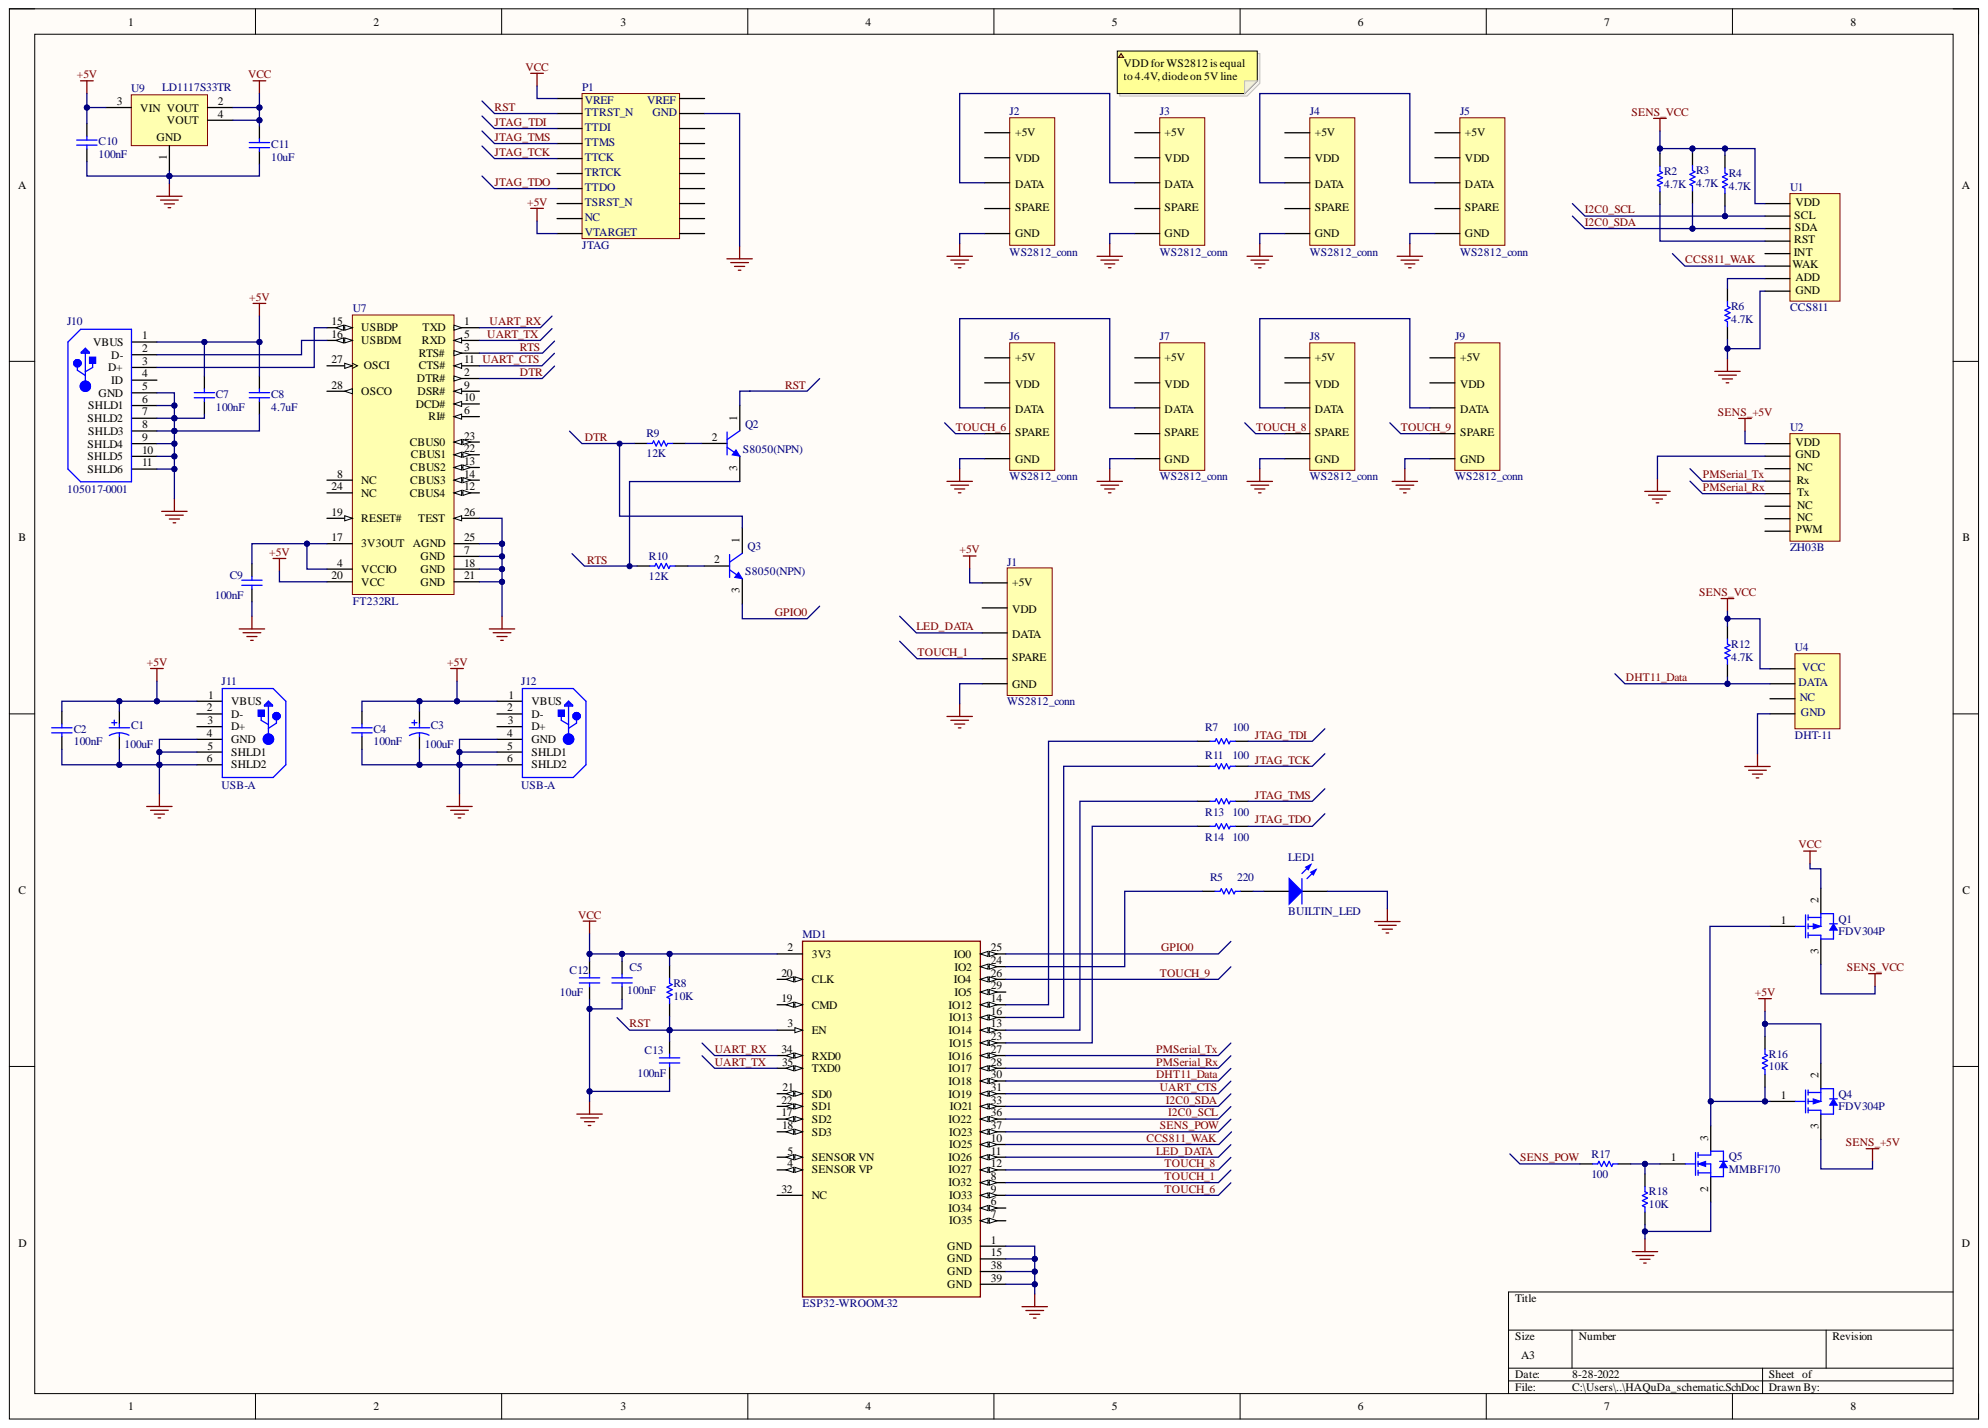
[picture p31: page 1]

ND NCRxTxNCNC PWM U2 ZH03B VDD GND SCL SDA WAK INT RST ADD U1 CCS81

3 | | 1 1
4 | 2 8 | 2

1 5
3 8
3 9

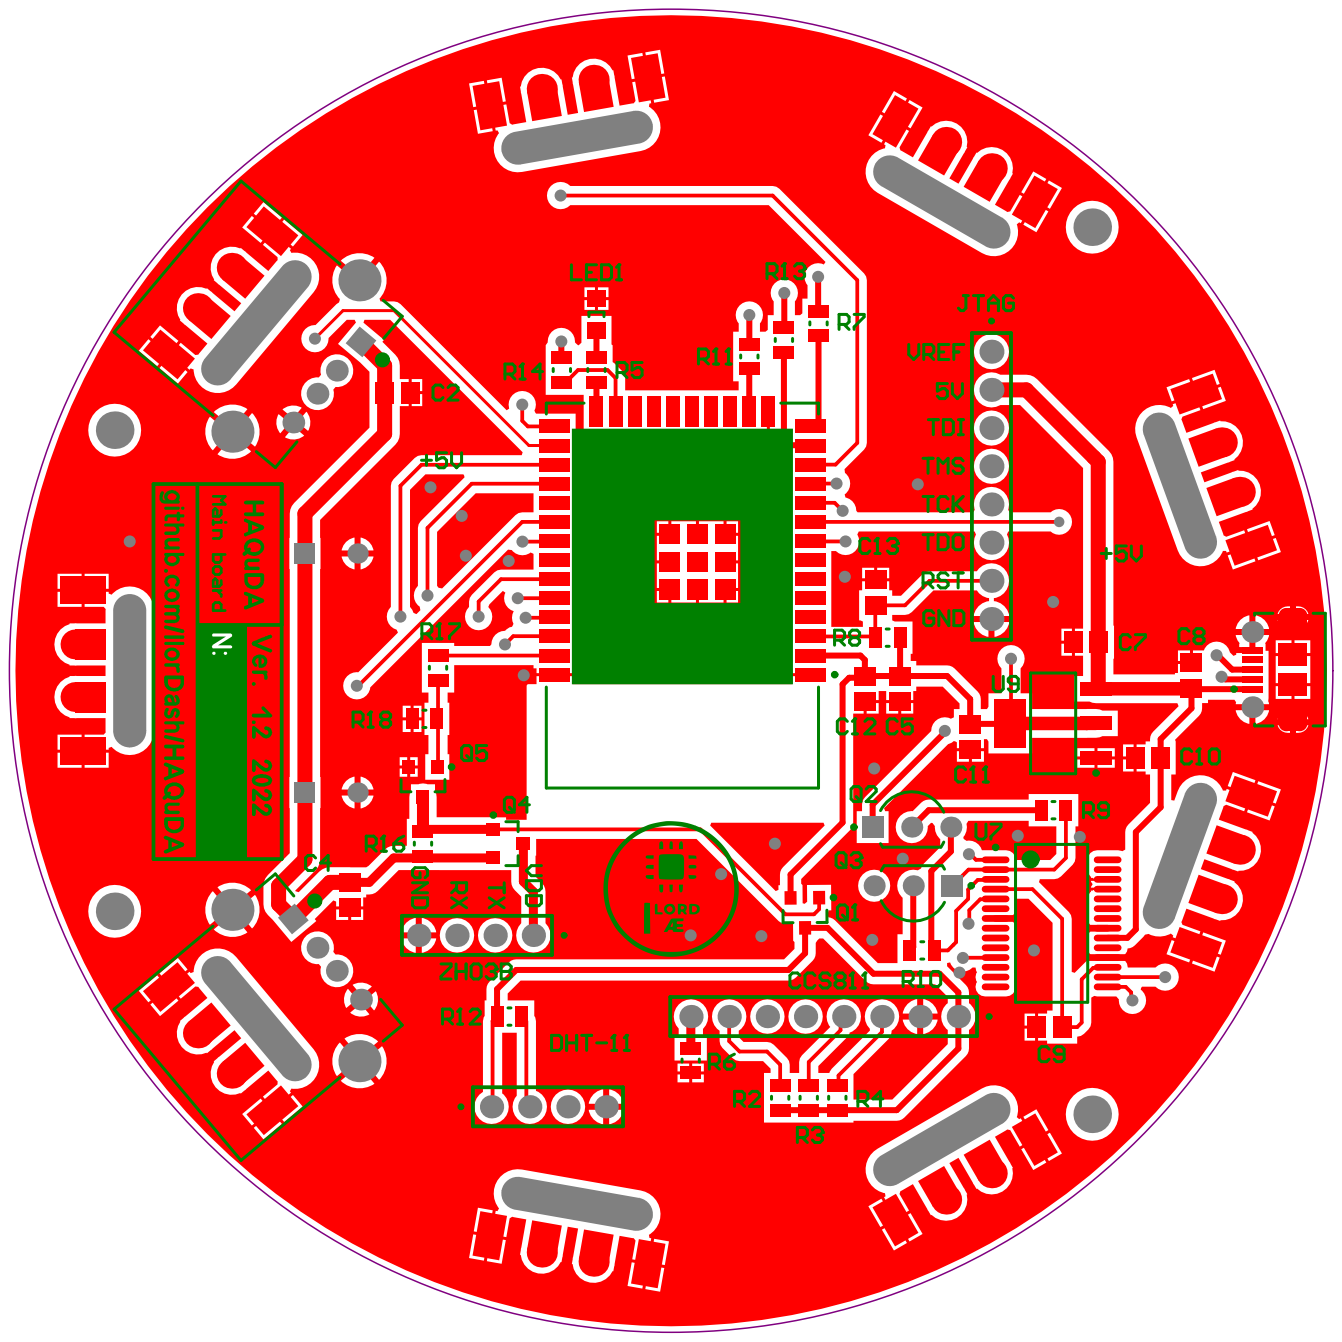
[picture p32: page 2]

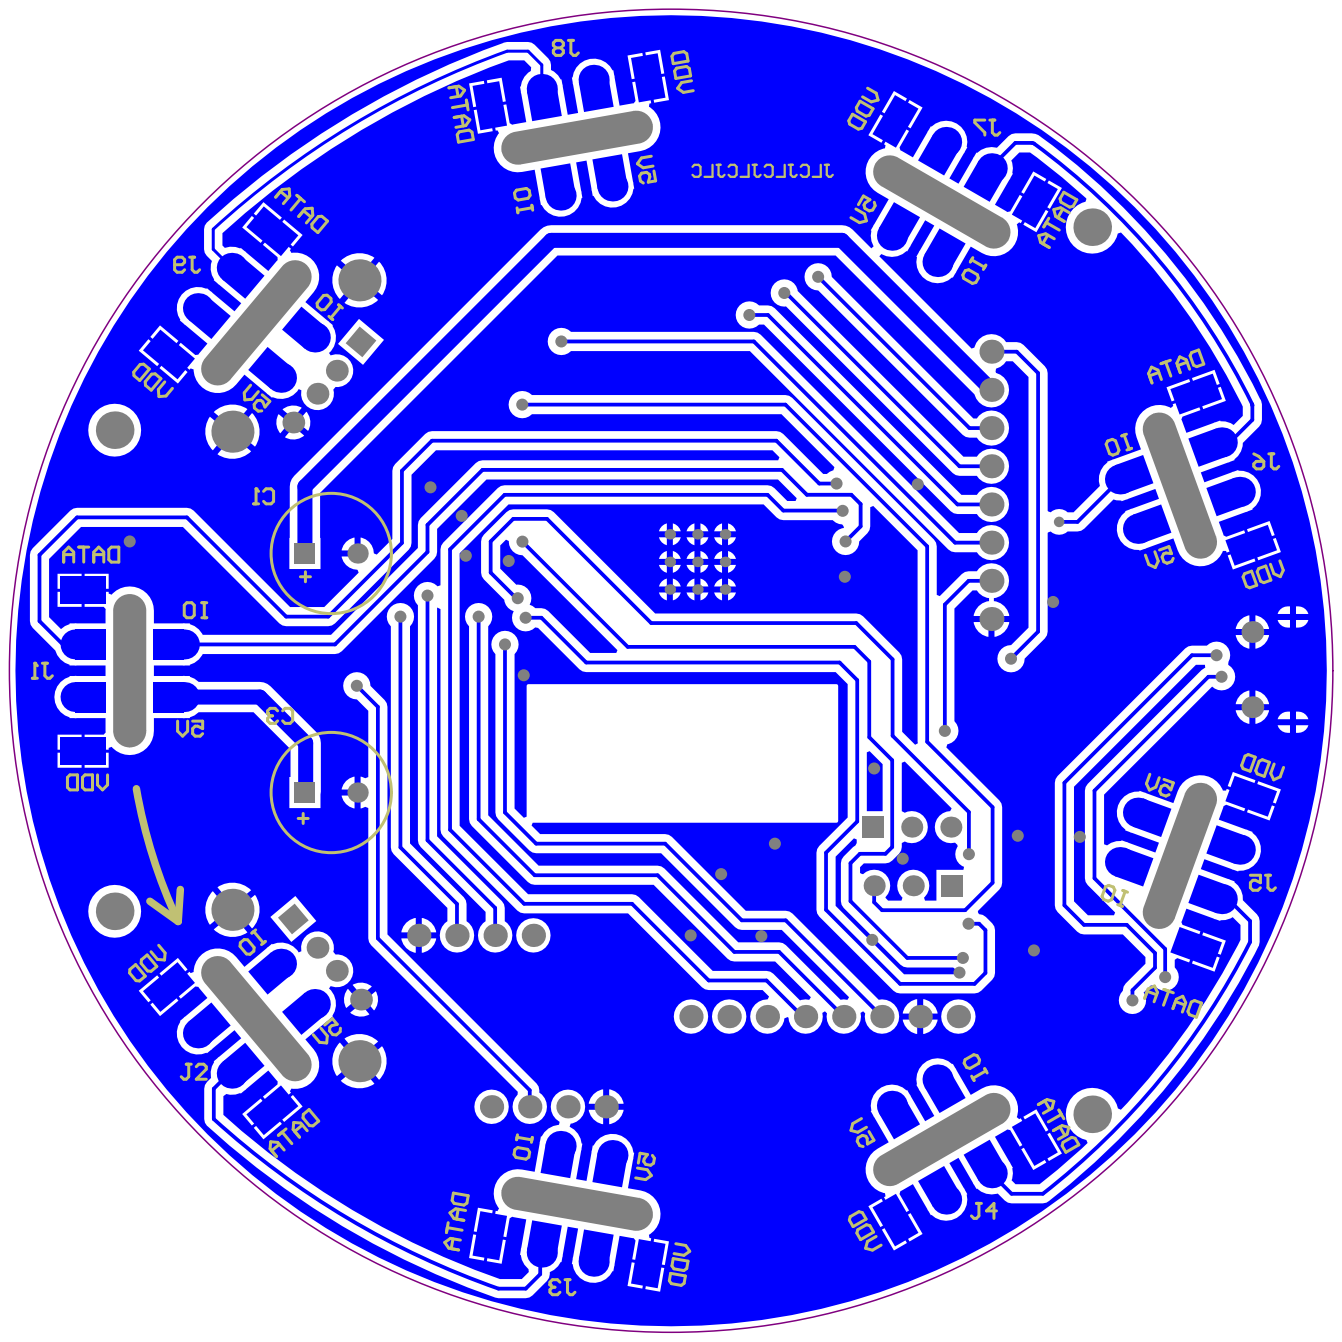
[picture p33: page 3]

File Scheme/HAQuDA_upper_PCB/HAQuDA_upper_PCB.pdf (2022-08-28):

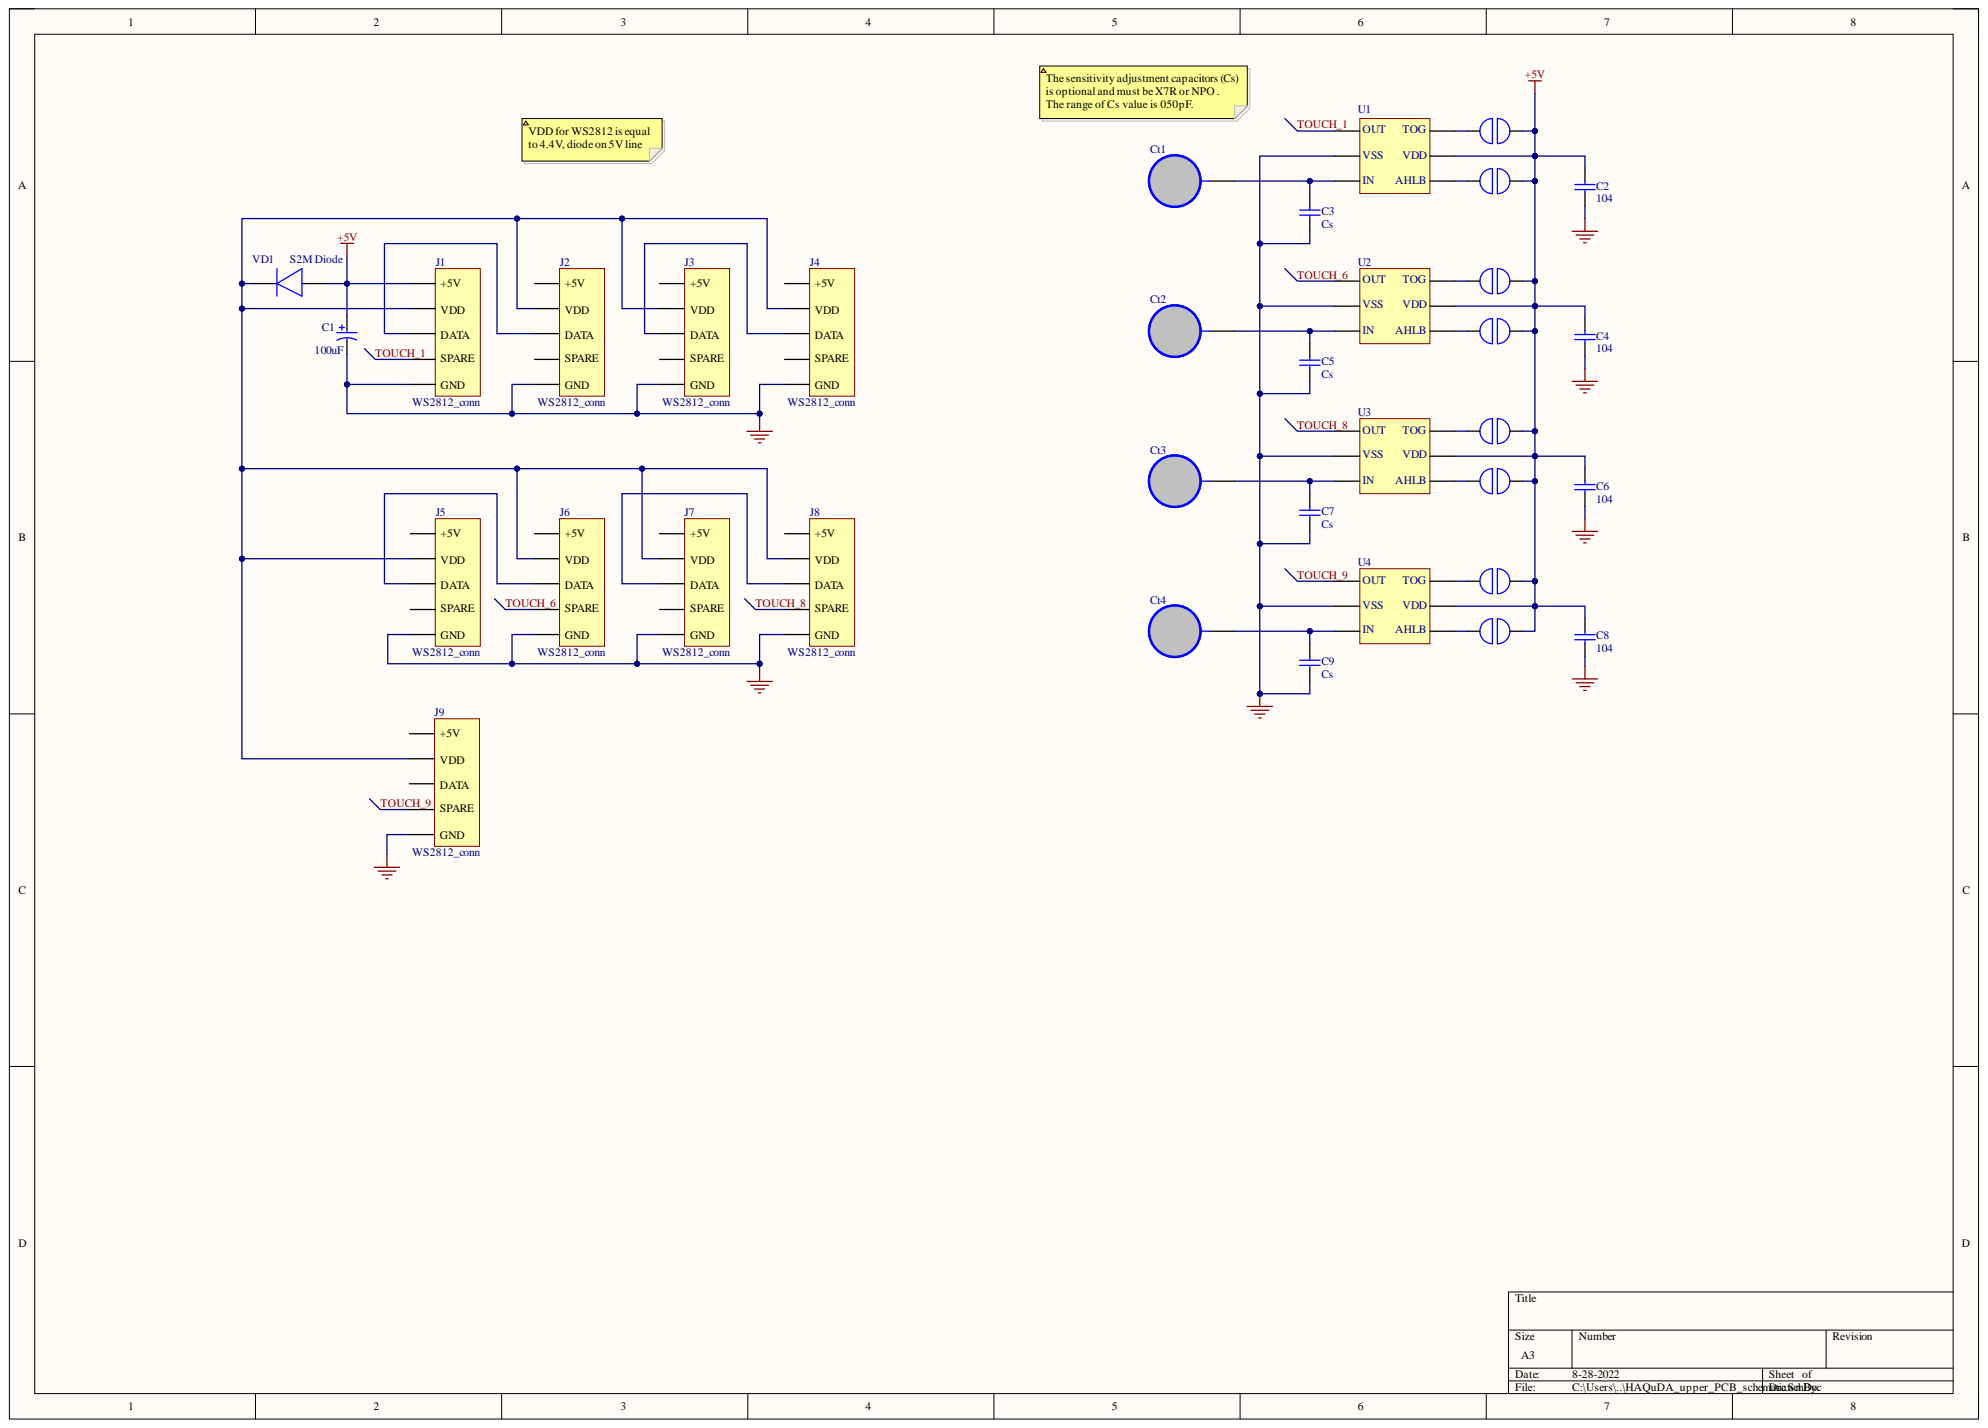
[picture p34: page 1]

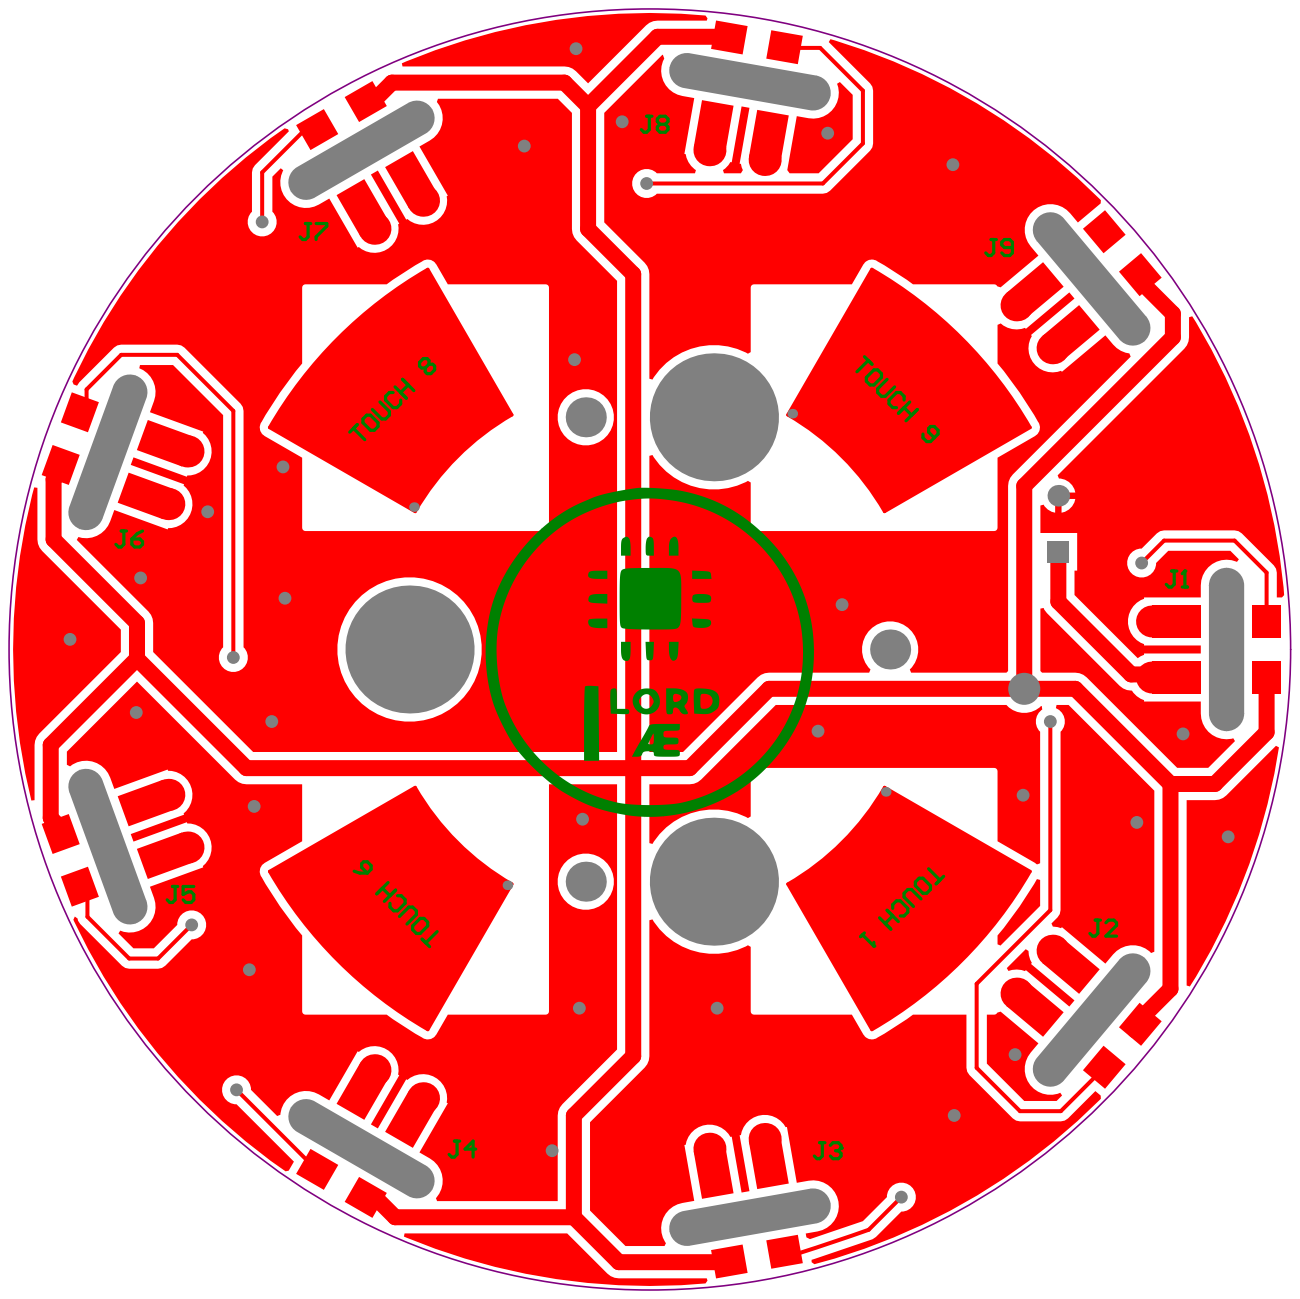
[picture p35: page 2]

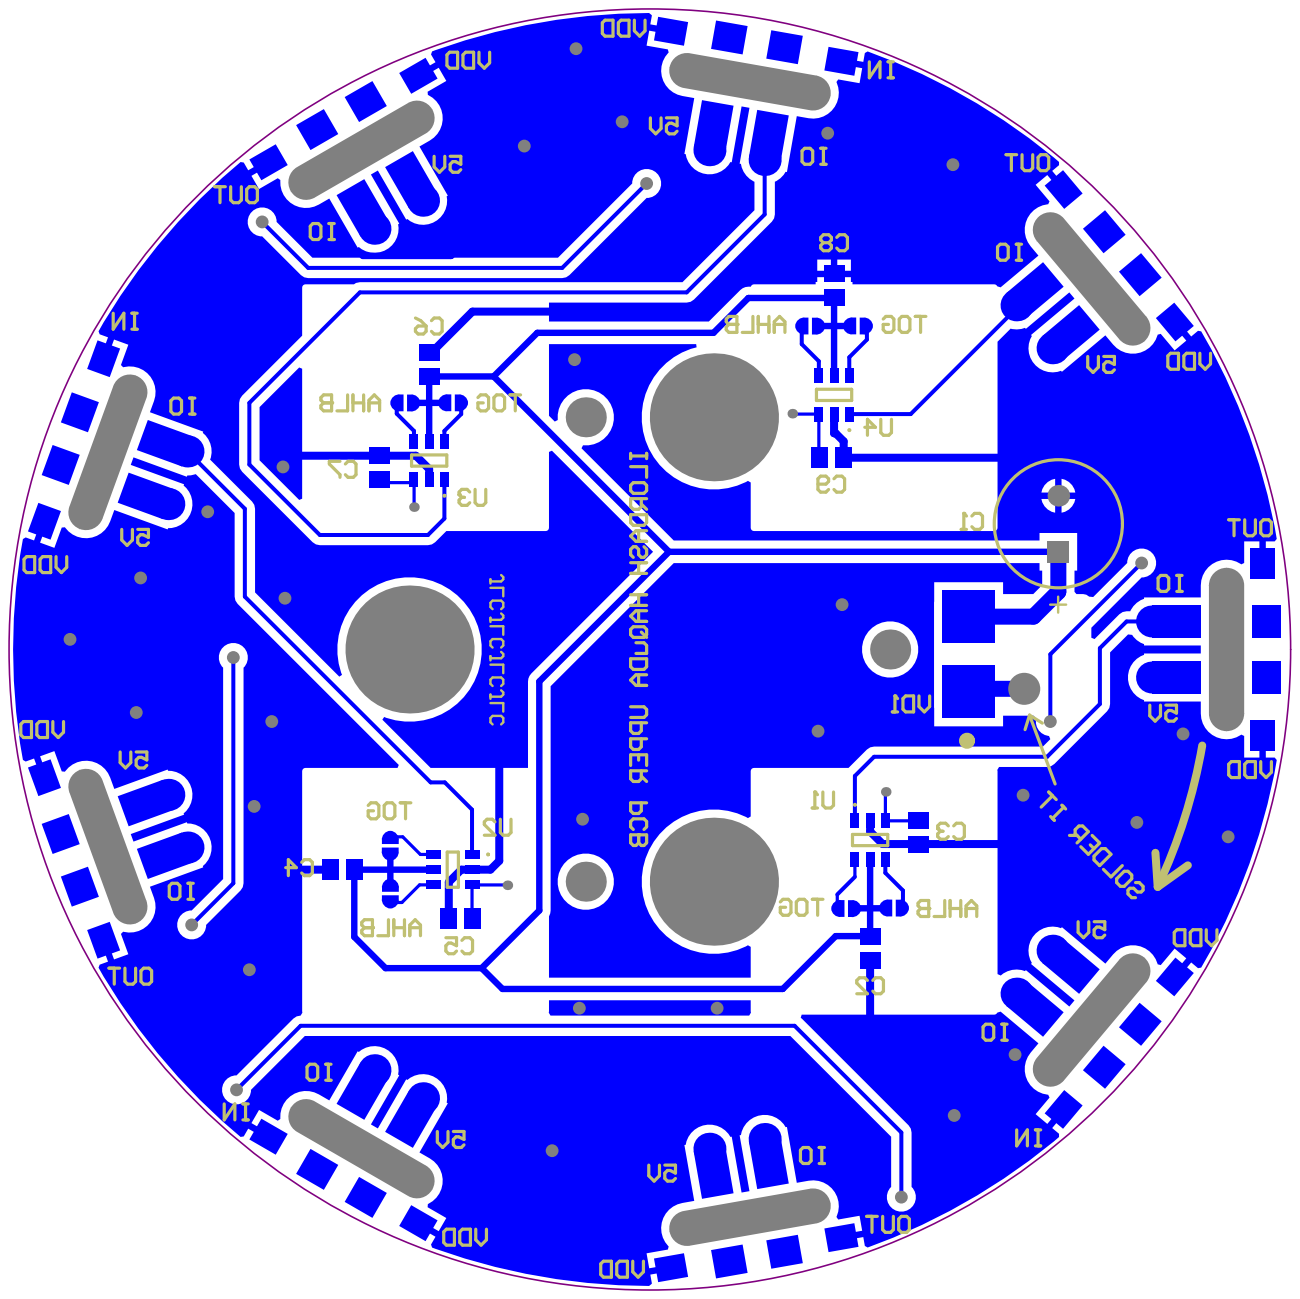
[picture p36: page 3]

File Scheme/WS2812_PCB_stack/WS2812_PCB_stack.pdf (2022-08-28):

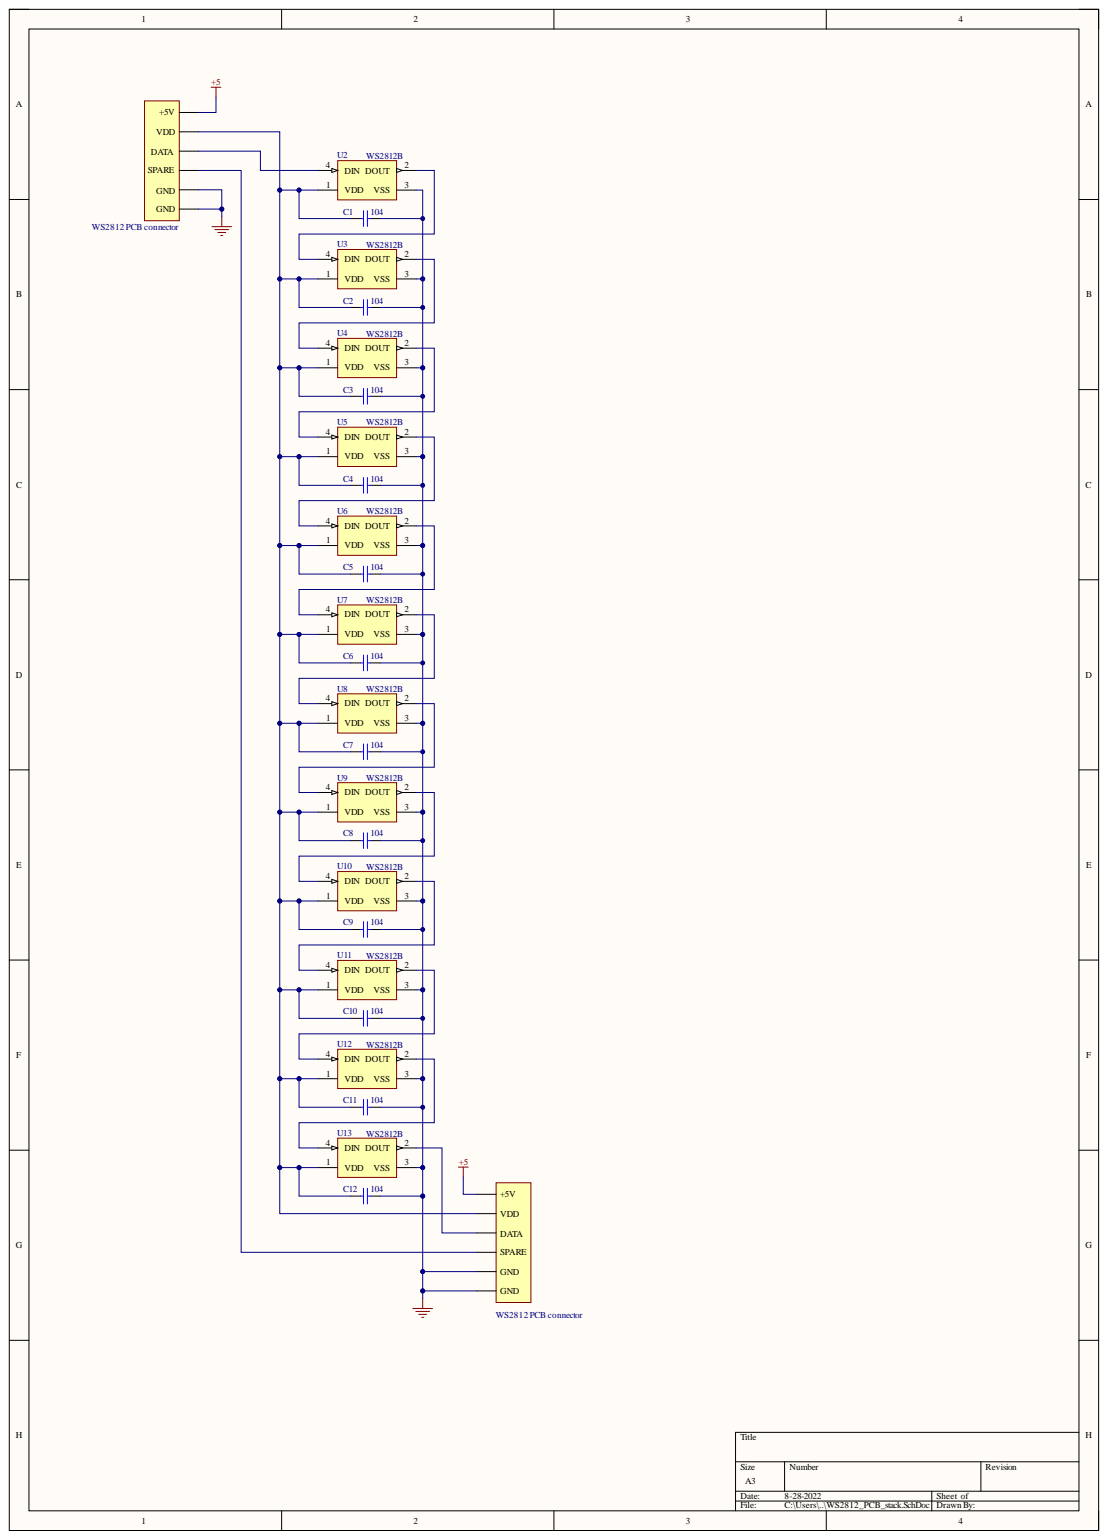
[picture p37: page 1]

Size A3 | Number | Revision

Date: 8-28-2022 | Sheet of
File: C:\Users\..\WS2812_PCB_stack.SchDoc | DrawnBy:

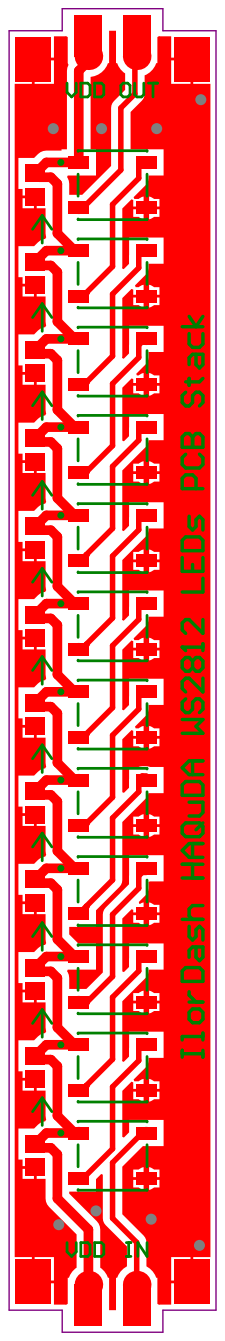
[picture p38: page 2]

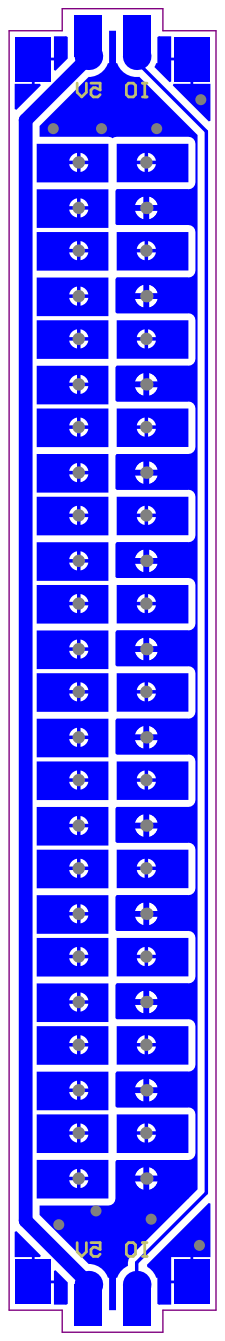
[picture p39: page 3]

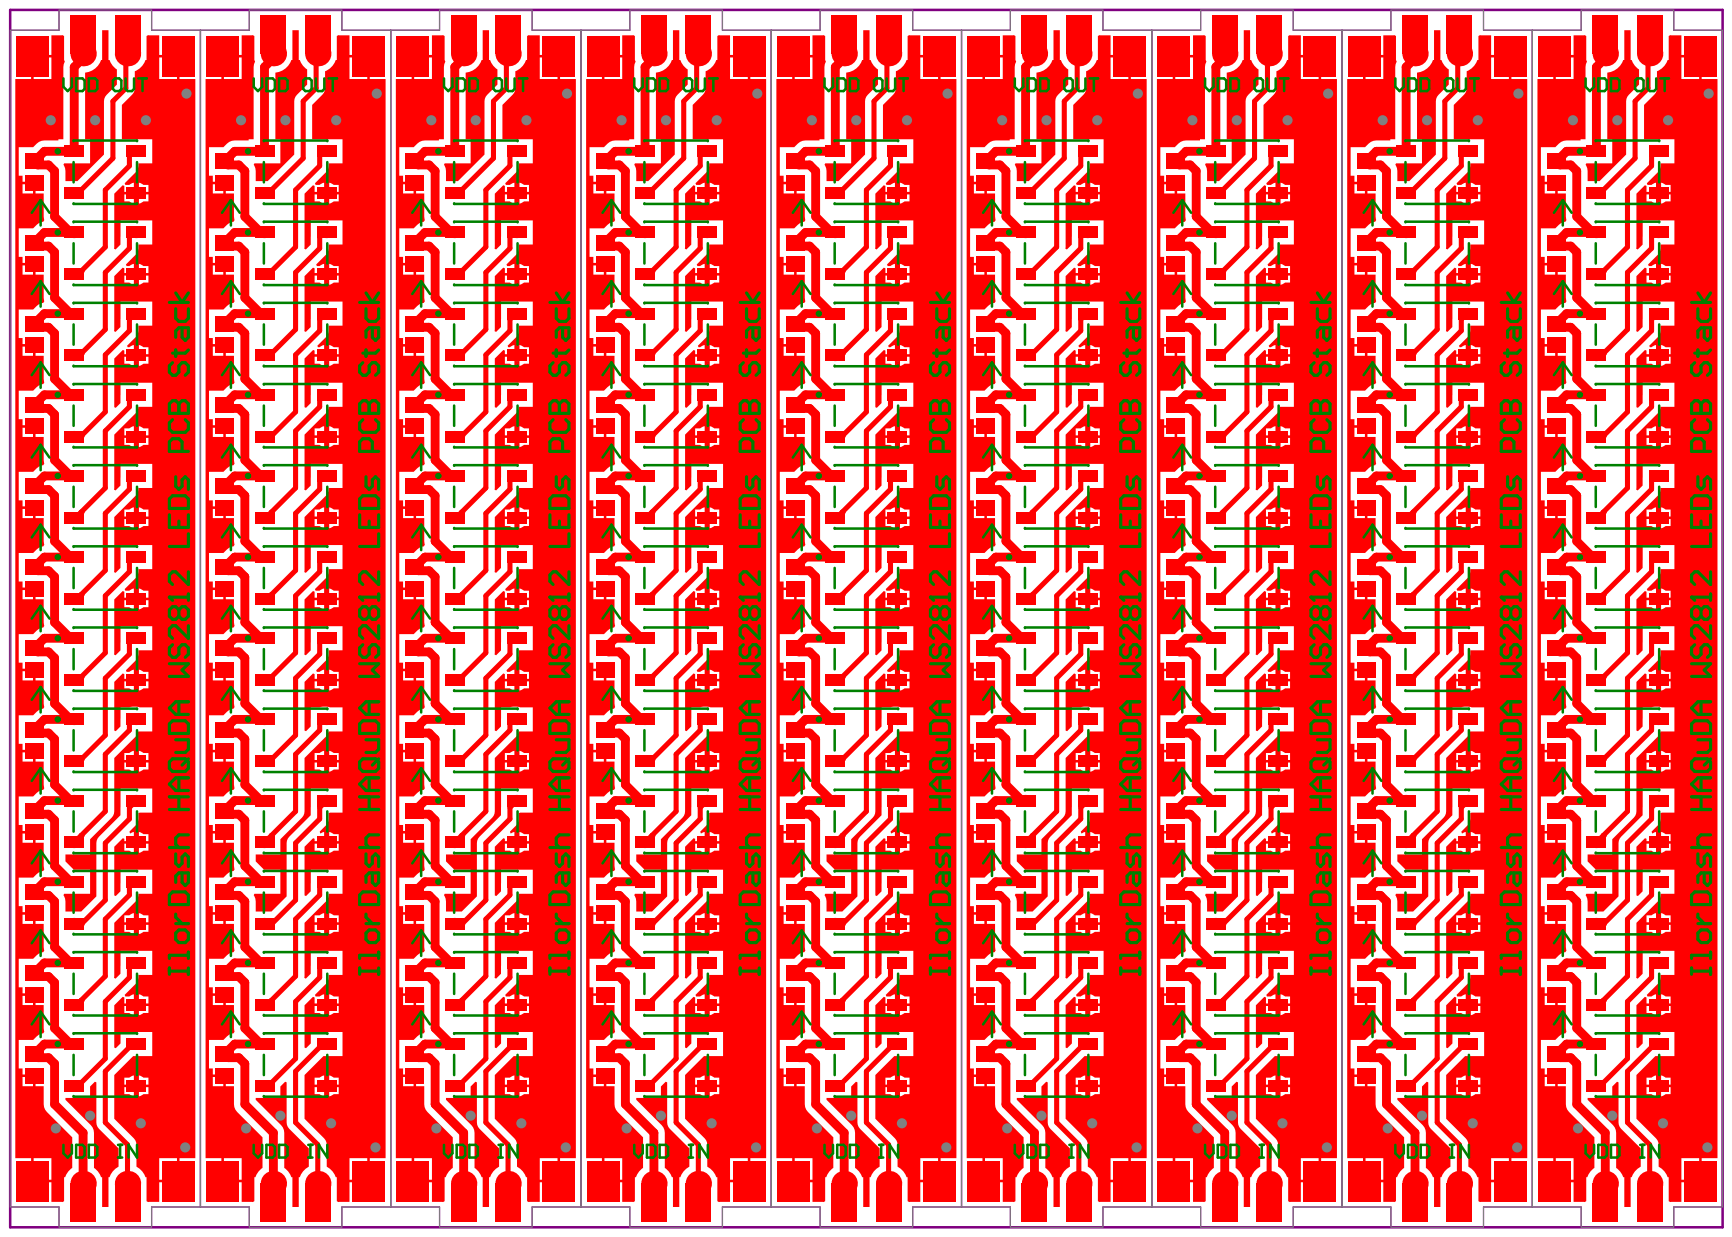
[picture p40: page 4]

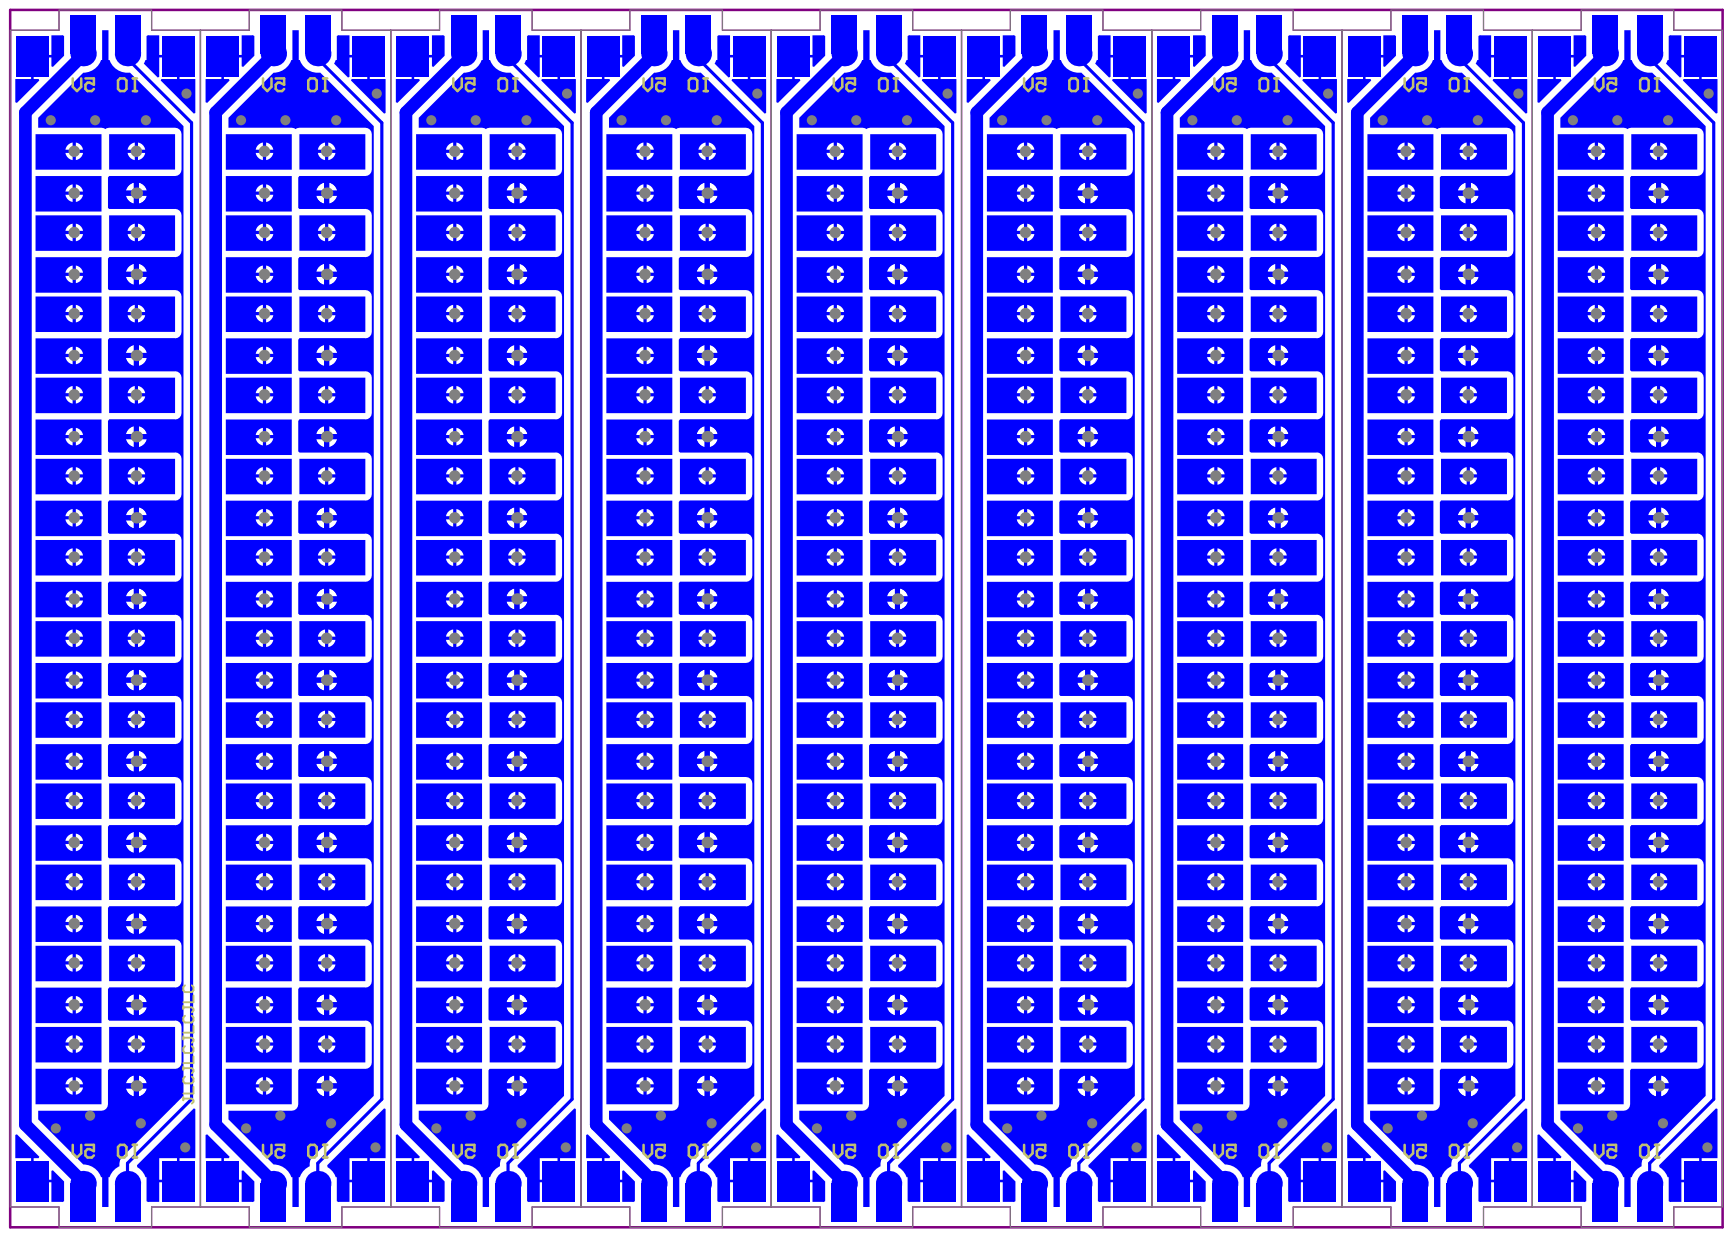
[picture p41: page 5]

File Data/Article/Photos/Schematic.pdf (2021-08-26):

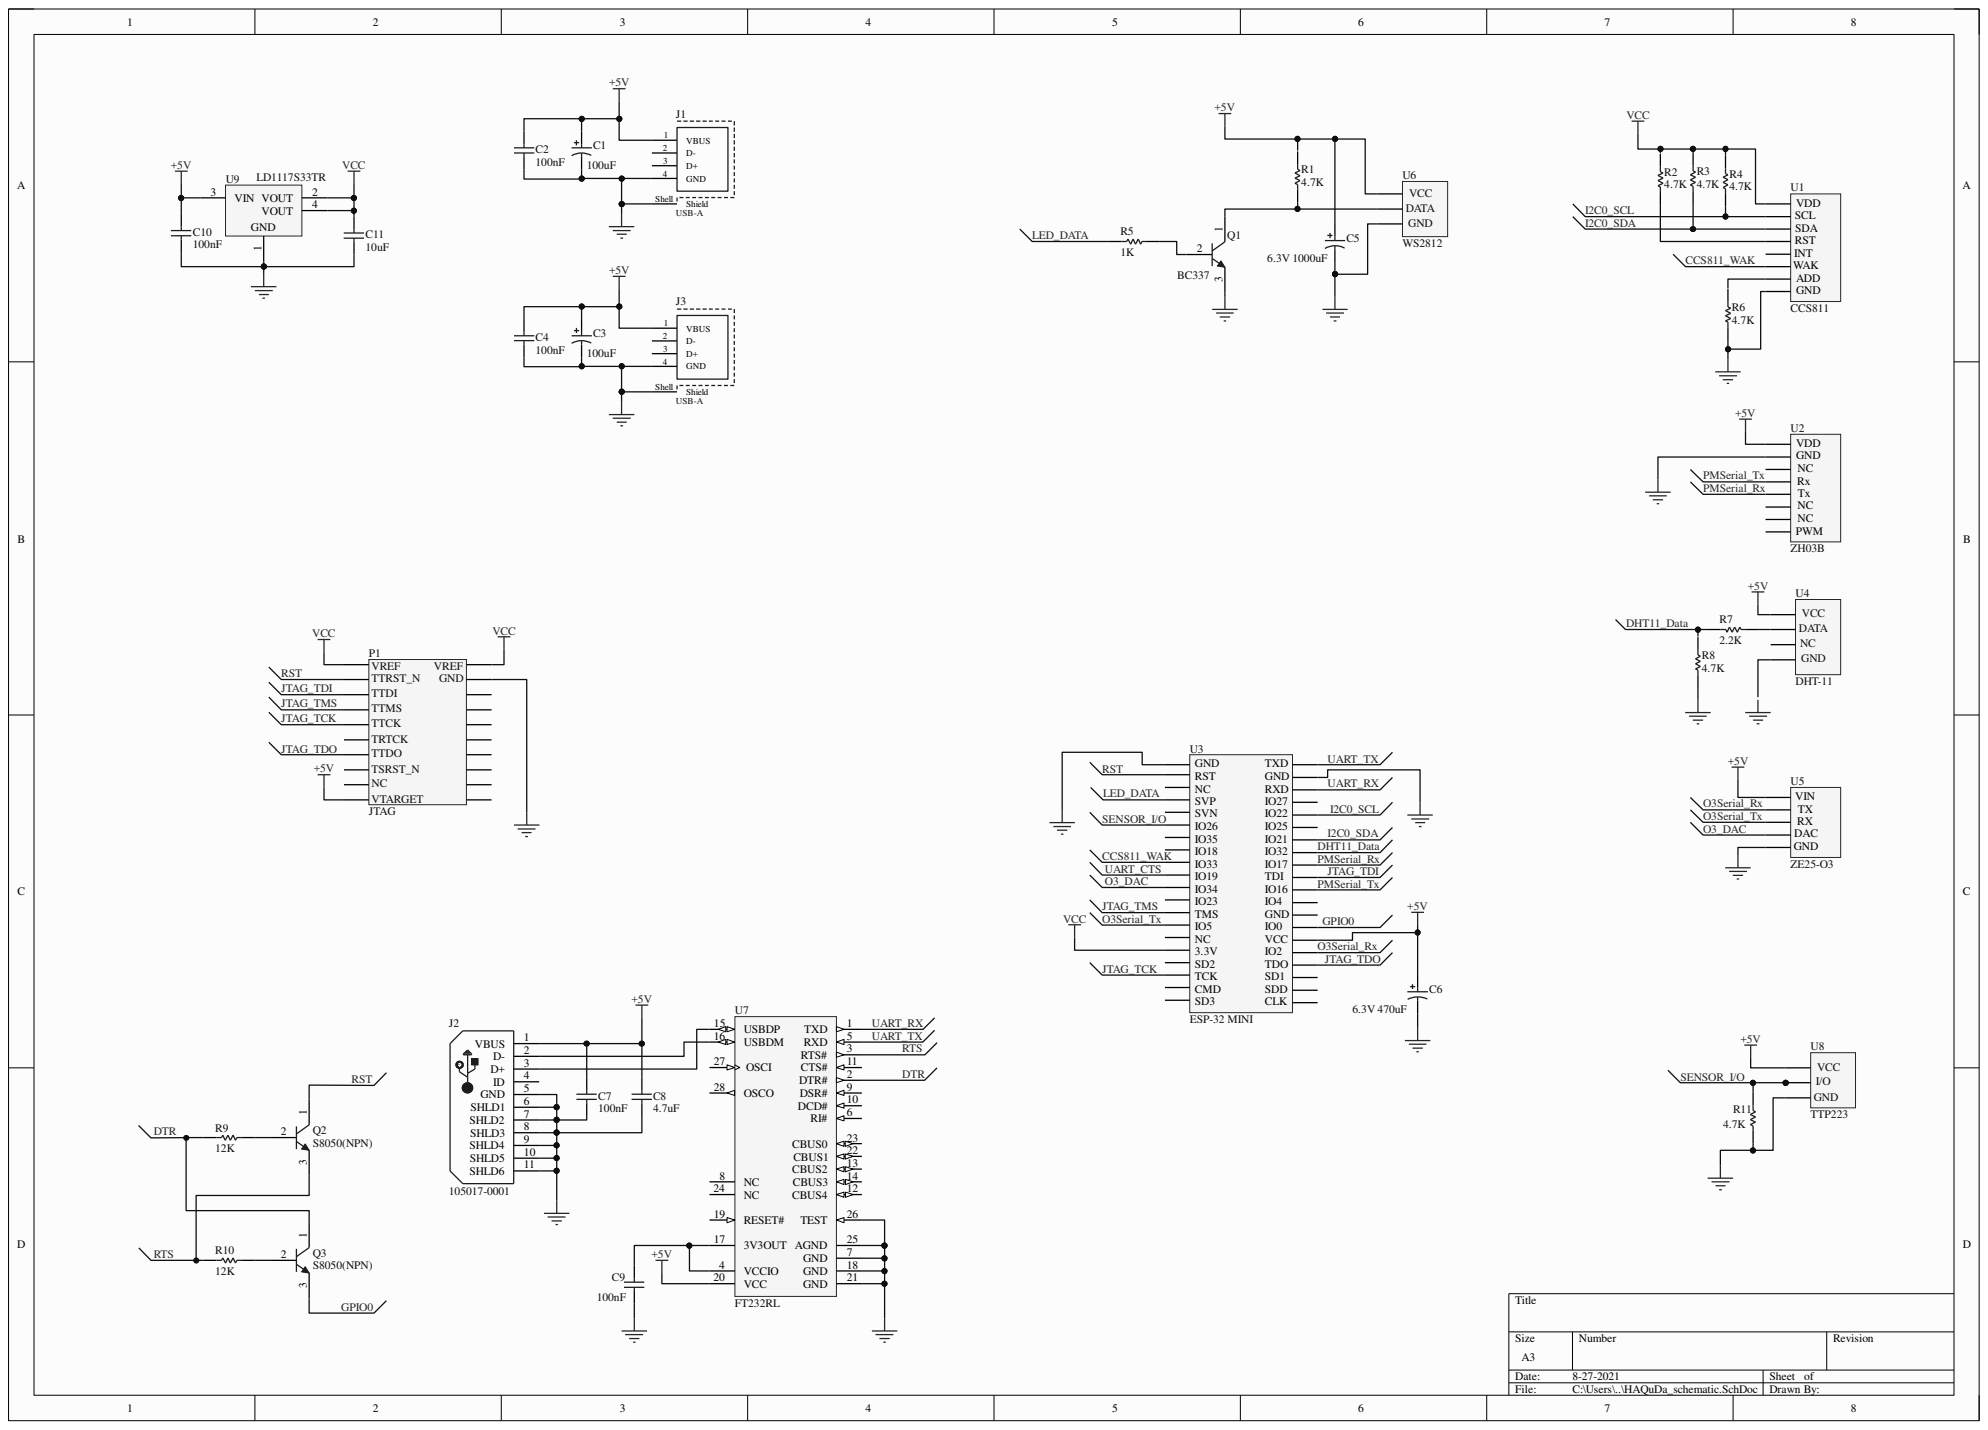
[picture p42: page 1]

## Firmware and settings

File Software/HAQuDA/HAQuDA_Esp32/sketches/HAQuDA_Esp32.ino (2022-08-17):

#include "Arduino.h"
#include "Main.h"

#include <WiFi.h>
#include <WebServer.h>
#include "WebPages.h"
#include <WiFiClient.h>
#include <BlynkSimpleEsp32.h>

#include "TimeHelper.h"
#include <SoftwareSerial.h>

#include "Sensors.h"
#include "WS2812.h"
#include "Tasks.h"

#include <NTPClient.h>
#include <WiFiUdp.h>

char BlynkAuth[] = BLYNK_AUTH;
char ssid_AP[] = "HAQuDA_ESP32";
char pass_AP[] = "1234567!";

IPAddress local_ip(192, 168, 0, 198);
IPAddress gateway(192, 168, 0, 1);
IPAddress subnet(255, 255, 255, 0);

char ssid[] = WIFI_SSID;
char pass[] = WIFI_PASS;

enum dispParams { total, eCO2, TVOC, PM2_5, temp, humid, noneParam };
dispParams whatParamDisp = noneParam;

enum dispMode { standard, multi, night, noneMode };
dispMode whatModeDisp = noneMode;

typedef struct {
	dispParams paramsArr[MULTI_MODE_PARAM_NUM];
	float dataArr[MULTI_MODE_PARAM_NUM];
	paramsDivideDots divideDotsArr[MULTI_MODE_PARAM_NUM];
} multiModeParamDispStruct;

multiModeParamDispStruct multiModeStruct;

paramsDivideDots temp_divideDots = {20, 26, 30};
paramsDivideDots humid_divideDots = {40, 60, 80};
paramsDivideDots eCO2_divideDots = {400, 1000, 5000};
paramsDivideDots TVOC_divideDots = {220, 660, 1000};
paramsDivideDots PM2_5_divideDots = {15, 20, 45};

dispEffects whatEffectDisp = noneEffect;

typedef struct {
	uint8_t timeFirstBorder;
	uint8_t timeSecondBorder;
} nightMode_timeBorderStruct;

nightMode_timeBorderStruct currentTimeBorder;

bool WiFiCredsFound = true;
bool WiFiConnected = false;

WidgetTerminal terminal(V0);
WebServer server(80);

// Define NTP Client to get time
WiFiUDP ntpUDP;
NTPClient timeClient(ntpUDP);

void WiFiStationConnected(WiFiEvent_t event, WiFiEventInfo_t info);
void WiFiStationDisconnected(WiFiEvent_t event, WiFiEventInfo_t info);
void UpdateVirtualPins();

void connectToWiFi(char *ssidLocal, char *passLocal);
void createAP();

void dispParam_WS2812();
void blynkPrintLog();

int firstDot;
int secondDot; // parametrs of dispParams
int thirdDot;

bool dispFirstParam = false;

void WiFi_handleConnection() {
	wl_status_t status = WiFi.status();
	int j = 0;
	while (WiFiCredsFound && (status != WL_CONNECTED)) {
		WS2812_clear();
		delay(100);
		connectToWiFi(ssid, pass);
		status = WiFi.status();
		if (status != WL_CONNECTED) {
			WS2812_setPixelColor(j, COLOR_YELLOW);
			log_i("Connecting to %s", ssidArr[i]);
			WiFi.reconnect();
			uint32_t timer = millis();

			while (status != WL_CONNECTED && !PeriodInRange(timer, 5000)) {
				status = WiFi.status();
				delay(200);
			}
			delay(500);
		}
		j++;
		if (j > LED_NUM_PIXELS) {
			WS2812_clear();
			delay(100);
			j = 0;
		}
	}
}

void connectToWiFi_AP() {
	wl_status_t status = WiFi.status();
	while (WiFiCredsFound && (status != WL_CONNECTED)) {
		connectToWiFi(ssid, pass);
		status = WiFi.status();
	}
}

void setup() {
	// Serial.begin(115200);

	pinMode(BUILTIN_LED, OUTPUT);
	digitalWrite(BUILTIN_LED, HIGH);

	pinMode(SENS_POW, OUTPUT);
	digitalWrite(SENS_POW, HIGH);

	currentTimeBorder.timeFirstBorder = 21;
	currentTimeBorder.timeSecondBorder = 9;

	WS2812_begin();
	
	WiFi_handleConnection();

	if (!sensorsBegin()) {
		WS2812_fillColor(COLOR_RED);
		terminal.println("FATAL ERROR: Failed to begin sensors");
		while (1) {
			digitalWrite(BUILTIN_LED, HIGH);
			delay(10);
			digitalWrite(BUILTIN_LED, LOW);
			delay(1000);
		}
	}

	createTasks();

	// Initialize a NTPClient to get time
	timeClient.begin();
	//	// Set offset time in seconds to adjust for your timezone, for example:
	//	// GMT +1 = 3600
	//	// GMT +8 = 28800
	//	// GMT +3 = 10800
	//	// GMT 0 = 0
	timeClient.setTimeOffset(10800);

	terminal.println("*************************");
	terminal.print("START LOGGING");

	whatModeDisp = multi;

	multiModeStruct.paramsArr[0] = temp;
	multiModeStruct.paramsArr[1] = eCO2;
	multiModeStruct.paramsArr[2] = PM2_5;

	multiModeStruct.divideDotsArr[0] = temp_divideDots;
	multiModeStruct.divideDotsArr[1] = eCO2_divideDots;
	multiModeStruct.divideDotsArr[2] = PM2_5_divideDots;

	dispParam_WS2812();
}

uint16_t measNum = 0;
uint32_t dispMeasTimer = 0;
uint32_t sensors_meas_time = 0;

void loop() {
	server.handleClient();
	if (!WiFiConnected) {
		WiFi_handleConnection();
	}
	if (!Blynk.connected()) {
		Blynk.connect();
	} else {
		Blynk.run();
	}
	vTaskDelay(100);

	if ((millis() - sensors_meas_time) > SENSORS_MEAS_PERIOD) {
		digitalWrite(BUILTIN_LED, HIGH);
		vTaskDelay(10);
		digitalWrite(BUILTIN_LED, LOW);
		getDHT11_meas();
		getCCS811_meas();
		getPM_meas();

		measNum++;
		blynkPrintLog();

		sensors_meas_time = millis();
	}

	if ((millis() - dispMeasTimer) > DISP_MEAS_PERIOD) {
		dispParam_WS2812();
		dispMeasTimer = millis();

		temp_meas.value = 0;
		temp_meas.measNum = 0;

		humid_meas.value = 0;
		humid_meas.measNum = 0;

		eCO2_meas.value = 0;
		eCO2_meas.measNum = 0;

		TVOC_meas.value = 0;
		TVOC_meas.measNum = 0;

		PM_2_5_meas.value = 0;
		PM_2_5_meas.measNum = 0;
	}
}

dispParams checkBadParam() {
	if ((temp_meas.value / temp_meas.measNum) >= temp_divideDots.thirdDot) {
		return temp;
	} else if ((humid_meas.value / humid_meas.measNum) >= humid_divideDots.thirdDot) {
		return humid;
	} else if ((eCO2_meas.value / eCO2_meas.measNum) >= eCO2_divideDots.thirdDot) {
		return eCO2;
	} else if ((TVOC_meas.value / TVOC_meas.measNum) >= TVOC_divideDots.thirdDot) {
		return TVOC;
	} else if ((PM_2_5_meas.value / PM_2_5_meas.measNum) >= PM2_5_divideDots.thirdDot) {
		return PM2_5;
	}
	return noneParam;
}

void standardDispParam_WS2812() {
	WS2812_clear();

	switch (whatParamDisp) {
		case total: {
			dispParams badParam = checkBadParam();
			switch (badParam) {
				case temp: {
					WS2812_showParams_standard(temp_meas.value / temp_meas.measNum, temp_divideDots);
					break;
				}
				case humid: {
					WS2812_showParams_standard(humid_meas.value / humid_meas.measNum, humid_divideDots);
					break;
				}
				case eCO2: {
					WS2812_showParams_standard(eCO2_meas.value / eCO2_meas.measNum, eCO2_divideDots);
					break;
				}
				case TVOC: {
					WS2812_showParams_standard(TVOC_meas.value / TVOC_meas.measNum, TVOC_divideDots);
					break;
				}
				case PM2_5: {
					WS2812_showParams_standard(PM_2_5_meas.value / PM_2_5_meas.measNum, PM2_5_divideDots);
					break;
				}
				case noneParam: {
					float paramsValuesArr[DISP_PARAMS_NUM];
					paramsValuesArr[0] = temp_meas.value / temp_meas.measNum;
					paramsValuesArr[1] = humid_meas.value / humid_meas.measNum;
					paramsValuesArr[2] = eCO2_meas.value / eCO2_meas.measNum;
					paramsValuesArr[3] = TVOC_meas.value / TVOC_meas.measNum;
					paramsValuesArr[4] = PM_2_5_meas.value / PM_2_5_meas.measNum;
					WS2812_showParams_standardTotal(paramsValuesArr);
					break;
				}
				default:
					break;
			}
			break;
		}
		case temp: {
			WS2812_showParams_standard(temp_meas.value / temp_meas.measNum, temp_divideDots);
			break;
		}
		case humid: {
			WS2812_showParams_standard(humid_meas.value / humid_meas.measNum, humid_divideDots);
			break;
		}
		case eCO2: {
			WS2812_showParams_standard(eCO2_meas.value / eCO2_meas.measNum, eCO2_divideDots);
			break;
		}
		case TVOC: {
			WS2812_showParams_standard(TVOC_meas.value / TVOC_meas.measNum, TVOC_divideDots);
			break;
		}
		case PM2_5: {
			WS2812_showParams_standard(PM_2_5_meas.value / PM_2_5_meas.measNum, PM2_5_divideDots);
			break;
		}

		default:
			break;
	}
}

uint8_t get_nightMode_hour(uint8_t curHour) {
	bool isBordersInDifferentDays = (currentTimeBorder.timeSecondBorder < currentTimeBorder.timeFirstBorder);

	if (isBordersInDifferentDays) {
		if ((curHour >= currentTimeBorder.timeFirstBorder) || (curHour <= currentTimeBorder.timeSecondBorder)) {
			int8_t hourDiff = curHour - currentTimeBorder.timeFirstBorder;
			hourDiff += (hourDiff < 0) ? 24 : 0;
			return hourDiff;
		} else {
			return 12;
		}
	} else {
		if ((curHour >= currentTimeBorder.timeFirstBorder) && (curHour <= currentTimeBorder.timeSecondBorder)) {
			int8_t hourDiff = curHour - currentTimeBorder.timeFirstBorder;
			return hourDiff;
		} else {
			return 12;
		}
	}
	return 12;
}

void nightDispParam_WS2812() {
	while (!timeClient.update()) {
		timeClient.forceUpdate();
	}
	// The formattedDate comes with the following format:
	// 2018-05-28T16:00:13Z
	// We need to extract date and time
	// Variables to save date and time
	String formattedDate;
	uint8_t curHour;

	formattedDate = timeClient.getFormattedDate();
	Serial.println(formattedDate);

	// Extract date
	int splitT = formattedDate.indexOf("T");
	int splitColon = formattedDate.indexOf(":");
	// Extract time
	curHour = formattedDate.substring(splitT + 1, splitColon).toInt();

	uint8_t nightMode_hour = get_nightMode_hour(curHour);
	WS2812_clear();

	if (whatParamDisp == temp) {
		WS2812_showParams_night(temp_meas.value / temp_meas.measNum, temp_divideDots, nightMode_hour);
		temp_meas.value = 0;
		temp_meas.measNum = 0;
	} else if (whatParamDisp == humid) {
		WS2812_showParams_night(humid_meas.value / humid_meas.measNum, humid_divideDots, nightMode_hour);
		humid_meas.value = 0;
		humid_meas.measNum = 0;
	} else if (whatParamDisp == eCO2) {
		WS2812_showParams_night(eCO2_meas.value / eCO2_meas.measNum, eCO2_divideDots, nightMode_hour);
		eCO2_meas.value = 0;
		eCO2_meas.measNum = 0;
	} else if (whatParamDisp == TVOC) {
		WS2812_showParams_night(TVOC_meas.value / TVOC_meas.measNum, TVOC_divideDots, nightMode_hour);
		TVOC_meas.value = 0;
		TVOC_meas.measNum = 0;
	} else if (whatParamDisp == PM2_5) {
		WS2812_showParams_night(PM_2_5_meas.value / PM_2_5_meas.measNum, PM2_5_divideDots, nightMode_hour);
		PM_2_5_meas.value = 0;
		PM_2_5_meas.measNum = 0;
	}
}

void multiDispParam_WS2812() {
	for (int i = 0; i < MULTI_MODE_PARAM_NUM; i++) {
		switch (multiModeStruct.paramsArr[i]) {
			case temp: {
				multiModeStruct.dataArr[i] = temp_meas.value / temp_meas.measNum;
				break;
			}
			case humid: {
				multiModeStruct.dataArr[i] = humid_meas.value / humid_meas.measNum;
				break;
			}
			case eCO2: {
				multiModeStruct.dataArr[i] = eCO2_meas.value / eCO2_meas.measNum;
				break;
			}
			case PM2_5: {
				multiModeStruct.dataArr[i] = PM_2_5_meas.value / PM_2_5_meas.measNum;
				break;
			}
			case TVOC: {
				multiModeStruct.dataArr[i] = TVOC_meas.value / TVOC_meas.measNum;
				break;
			}
			default:
				break;
		}
	}
	WS2812_clear();
	WS2812_showParams_multi(multiModeStruct.dataArr, multiModeStruct.divideDotsArr);
}

void dispParam_WS2812() {
	switch (whatModeDisp) {
		case standard: {
			standardDispParam_WS2812();
			break;
		}
		case multi: {
			multiDispParam_WS2812();
			break;
		}
		case night: {
			nightDispParam_WS2812();
			break;
		}
		default:
			break;
	}
}

void checkIfMeasCorrect() {
	if (!eCO2_meas.newMeasDone) {
		terminal.println("ERROR: Failed to get eCO2 measurment");
	}
	if (!TVOC_meas.newMeasDone) {
		terminal.println("ERROR: Failed to get TVOC measurment");
	}
	if (!PM_2_5_meas.newMeasDone) {
		terminal.println("ERROR: Failed to get PM 2.5 measurment");
	}
	if (!temp_meas.newMeasDone) {
		terminal.println("ERROR: Failed to get TEMP measurment");
	}
	if (!humid_meas.newMeasDone) {
		terminal.println("ERROR: Failed to get HUMID measurment");
	}
	terminal.flush();

	eCO2_meas.newMeasDone = false;
	TVOC_meas.newMeasDone = false;
	PM_2_5_meas.newMeasDone = false;
	temp_meas.newMeasDone = false;
	humid_meas.newMeasDone = false;
}

void blynkPrintLog() {
	terminal.println();
	terminal.println("----------------------------");
	terminal.print(measNum);
	terminal.println(" - measurment");

	checkIfMeasCorrect();

	terminal.print("Temp: ");
	terminal.print(temp_meas.value / temp_meas.measNum);
	terminal.println("  C");
	terminal.print("Humid: ");
	terminal.print(humid_meas.value / humid_meas.measNum);
	terminal.println("  %");
	terminal.println();

	terminal.flush();

	terminal.print("PM1.0: ");
	terminal.print(PM_1_0_meas.value / PM_1_0_meas.measNum);
	terminal.println("  ug/m3");
	terminal.print("PM2.5: ");
	terminal.print(PM_2_5_meas.value / PM_2_5_meas.measNum);
	terminal.println("  ug/m3");
	terminal.print("PM1 0: ");
	terminal.print(PM_10_meas.value / PM_10_meas.measNum);
	terminal.println("  ug/m3");
	terminal.println();

	terminal.flush();

	terminal.print("eCO2: ");
	terminal.print(eCO2_meas.value / eCO2_meas.measNum);
	terminal.println("  ppm");
	terminal.println();

	terminal.print("TVOC: ");
	terminal.print(TVOC_meas.value / TVOC_meas.measNum);
	terminal.println("  ppb");
	terminal.println();

	terminal.flush();

	if (whatModeDisp == standard) {
		terminal.println("Display standard");
		switch (whatParamDisp) {
			case total:
				terminal.println("Display total quality");
				break;
			case temp:
				terminal.println("Display temperature");
				break;
			case humid:
				terminal.println("Display humidity");
				break;
			case eCO2:
				terminal.println("Display eCO2");
				break;
			case TVOC:
				terminal.println("Display TVOC");
				break;
			case PM2_5:
				terminal.println("Display PM2_5");
				break;
			default:
				terminal.println("Display none parametr");
		}
	} else if (whatModeDisp == multi) {
		terminal.println("Display multi");
		for (int i = 0; i < MULTI_MODE_PARAM_NUM; i++) {
			switch (multiModeStruct.paramsArr[i]) {
				case total:
					terminal.println("Display total quality");
					break;
				case temp:
					terminal.println("Display temperature");
					break;
				case humid:
					terminal.println("Display humidity");
					break;
				case eCO2:
					terminal.println("Display eCO2");
					break;
				case TVOC:
					terminal.println("Display TVOC");
					break;
				case PM2_5:
					terminal.println("Display PM2_5");
					break;
				default:
					terminal.println("Display none parametr");
			}
		}
	} else if (whatModeDisp == night) {
		switch (whatParamDisp) {
			case total:
				terminal.println("Display total quality");
				break;
			case temp:
				terminal.println("Display temperature");
				break;
			case humid:
				terminal.println("Display humidity");
				break;
			case eCO2:
				terminal.println("Display eCO2");
				break;
			case TVOC:
				terminal.println("Display TVOC");
				break;
			case PM2_5:
				terminal.println("Display PM2_5");
				break;
			default:
				terminal.println("Display none parametr");
		}
	} else {
		switch (whatEffectDisp) {
			case snake:
				terminal.println("Display snake effect");
				break;
			case randomPixel:
				terminal.println("Display random pixel effect");
				break;
			case fade:
				terminal.println("Display fade effect");
				break;
			case christmasTree:
				terminal.println("Display Christmas Tree effect");
				break;
			default:
				break;
		}
	}

	terminal.flush();
}

void createAP() {
	WiFi.mode(WIFI_AP);
	WiFi.softAP(ssid_AP, pass_AP);
	delay(2000);
	WiFi.softAPConfig(local_ip, gateway, subnet);
	// IPAddress ip_address = WiFi.softAPIP(); // IP Address of our accesspoint
	delay(100);
}

void connectToWiFi(char *ssidLocal, char *passLocal) {
	WiFi.mode(WIFI_STA);
	WiFi.begin(ssidLocal, passLocal, 0, 0);
	WiFi.onEvent(WiFiStationConnected, SYSTEM_EVENT_STA_CONNECTED);
	WiFi.onEvent(WiFiStationDisconnected, SYSTEM_EVENT_STA_DISCONNECTED);

	Blynk.config(BlynkAuth, BLYNK_DEFAULT_DOMAIN, BLYNK_DEFAULT_PORT);
}

void setWiFiCreds(String ssidLocal, String passLocal) {
	if (server.hasArg("ssid") && server.hasArg("password")) {
		ssidLocal = server.arg("ssid");
		passLocal = server.arg("password");
		WiFiCredsFound = true;
		server.send(200, "text/html", WiFiCredsPage);
		// server.stop();
	} else {
		// If one of the creds is missing, go back to form page
		server.send(200, "text/html", WiFiCredsPage);
	}
}

void handle_NotFound() {
	server.send(404, "text/plain", "Not found");
}

void WiFiStationConnected(WiFiEvent_t event, WiFiEventInfo_t info) {
	WS2812_fillColor(COLOR_GREEN);
	delay(1000);
	WS2812_clear();
	delay(100);
	WiFiConnected = true;
}

void WiFiStationDisconnected(WiFiEvent_t event, WiFiEventInfo_t info) {
	WiFiConnected = false;
}

BLYNK_WRITE(V1) {
	int red = param[0].asInt();
	int green = param[1].asInt();
	int blue = param[2].asInt();
	log_i("V0, r: %d, g: %d, b: %d,", red, green, blue);
	uint32_t color = ((uint32_t)red << 16) | ((uint32_t)green << 8) | blue;
	WS2812_fillColor(color);
	delay(100);
	whatModeDisp = noneMode;
	whatEffectDisp = noneEffect;
}

BLYNK_WRITE(V2) {
	WS2812_setBrightnessPerCent(param.asInt());

	if (whatModeDisp == night) { // fix bug when white columns are off with brightness < 22%
		nightDispParam_WS2812();
	}
}

BLYNK_WRITE(V3) {
	switch (param.asInt()) {
		case 1: {
			whatModeDisp = standard;
			break;
		}
		case 2: {
			whatModeDisp = multi;

			multiModeStruct.paramsArr[0] = temp;
			multiModeStruct.paramsArr[1] = eCO2;
			multiModeStruct.paramsArr[2] = PM2_5;

			multiModeStruct.divideDotsArr[0] = temp_divideDots;
			multiModeStruct.divideDotsArr[1] = eCO2_divideDots;
			multiModeStruct.divideDotsArr[2] = PM2_5_divideDots;

			break;
		}
		case 3: {
			whatModeDisp = night;
			break;
		}
		default:
			whatModeDisp = noneMode;
	}
	whatEffectDisp = noneEffect;
	vTaskDelay(1000 / portTICK_PERIOD_MS);
	dispParam_WS2812();
}

BLYNK_WRITE(V4) {
	switch (param.asInt()) {
		case 1: {
			whatParamDisp = temp;
			break;
		}
		case 2: {
			whatParamDisp = humid;
			break;
		}
		case 3: {
			whatParamDisp = eCO2;
			break;
		}
		case 4: {
			whatParamDisp = TVOC;
			break;
		}
		case 5: {
			whatParamDisp = PM2_5;
			break;
		}
		case 6: {
			whatParamDisp = total;
			break;
		}
		default:
			whatParamDisp = noneParam;
	}
	whatEffectDisp = noneEffect;
	delay(200);
	dispParam_WS2812();
}

BLYNK_WRITE(V5) {
	switch (param.asInt()) {
		case 1: { // Item 3
			whatEffectDisp = snake;
			break;
		}
		case 2: { // Item 3
			whatEffectDisp = randomPixel;
			break;
		}
		case 3: { // Item 1
			whatEffectDisp = fade;
			break;
		}
		case 4: { // Item 2
			whatEffectDisp = christmasTree;
			break;
		}
		default:
			whatEffectDisp = noneEffect;
	}
	whatModeDisp = noneMode;
}

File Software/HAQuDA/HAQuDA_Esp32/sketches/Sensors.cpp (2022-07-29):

#include "Sensors.h"

#define DHTPIN 18
#define DHTTYPE DHT11

#define ZH03B_RX_PIN 17
#define ZH03B_TX_PIN 16

#define CCS811_WAK 5

Adafruit_CCS811 CCS811;

measStruct eCO2_meas;
measStruct TVOC_meas;
measStruct PM_1_0_meas; // define PM1.0 value of the air detector module
measStruct PM_2_5_meas; // define PM2.5 value of the air detector module
measStruct PM_10_meas;  // define PM10 value of the air detector module
measStruct temp_meas;   // define PM10 value of the air detector module
measStruct humid_meas;  // define PM10 value of the air detector module

byte O3_buf[9];

DHT dht(DHTPIN, DHTTYPE);

SoftwareSerial PMSerial;

bool sensorsBegin() {
	PMSerial.begin(9600, SWSERIAL_8N1, ZH03B_RX_PIN, ZH03B_TX_PIN, false, 256);
	PMSerial.setTimeout(100);

	pinMode(CCS811_WAK, OUTPUT);
	digitalWrite(CCS811_WAK, LOW);

	eCO2_meas.measNum = 0;
	eCO2_meas.value = 0;
	eCO2_meas.newMeasDone = false;

	TVOC_meas.measNum = 0;
	TVOC_meas.value = 0;
	TVOC_meas.newMeasDone = false;

	PM_1_0_meas.measNum = 0;
	PM_1_0_meas.value = 0;
	PM_1_0_meas.newMeasDone = false;

	PM_10_meas.measNum = 0;
	PM_10_meas.value = 0;
	PM_10_meas.newMeasDone = false;

	PM_2_5_meas.measNum = 0;
	PM_2_5_meas.value = 0;
	PM_2_5_meas.newMeasDone = false;

	temp_meas.measNum = 0;
	temp_meas.value = 0;
	temp_meas.newMeasDone = false;

	humid_meas.measNum = 0;
	humid_meas.value = 0;
	humid_meas.newMeasDone = false;

	if (!CCS811.begin()) {
		// Serial.println("Failed to start sensor! Please check your wiring.");
		return false;
	}

	dht.begin();

	uint32_t fisrtDispMeasTimer = millis();

	while ((!temp_meas.newMeasDone || !eCO2_meas.newMeasDone || !PM_2_5_meas.newMeasDone) && (millis() - fisrtDispMeasTimer) < FIRST_MEAS_TIMEOUT) {
		vTaskDelay(500);
		getDHT11_meas();
		getCCS811_meas();
		getPM_meas();
	}

	return true;
}

bool getCCS811_meas() {
	if (CCS811.available()) {
		if (!CCS811.readData()) {
			eCO2_meas.value += CCS811.geteCO2(); // returns eCO2 reading
			eCO2_meas.measNum++;
			eCO2_meas.newMeasDone = true;
			TVOC_meas.value += CCS811.getTVOC(); // return TVOC reading
			TVOC_meas.measNum++;
			TVOC_meas.newMeasDone = true;
			return true;
		}
	}
	eCO2_meas.value = 0; // returns eCO2 reading
	eCO2_meas.measNum = 0;
	eCO2_meas.newMeasDone = false;
	TVOC_meas.value = 0; // return TVOC reading
	TVOC_meas.measNum = 0;
	TVOC_meas.newMeasDone = false;
	return false;
}

const uint16_t PmSerialDataMarker = 0x4D42;
typedef struct {
	uint16_t length;
	uint16_t reserv0;
	uint16_t reserv1;
	uint16_t reserv2;
	uint16_t pm1_0;
	uint16_t pm2_5;
	uint16_t pm10;
	uint16_t reserv3;
	uint16_t reserv4;
	uint16_t reserv5;
} __attribute__((packed)) TPmSerialData, *PTPmSerialData;

uint16_t calcPM_checkSum(uint8_t *buffer, int size) {
	uint16_t sum = 0;

	for (int i = 0; i < size; i++) {
		sum += *buffer++;
	}
	return sum;
}

bool readPM_data(PTPmSerialData pPmSerialData) {
	uint16_t checkSum;
	bool findMarker_result = PMSerial.find((uint8_t *)&PmSerialDataMarker, sizeof(PmSerialDataMarker));
	if (!findMarker_result) {
		return false;
	}

	int readData_result = PMSerial.readBytes((uint8_t *)pPmSerialData, sizeof(*pPmSerialData));
	if (readData_result != sizeof(*pPmSerialData)) {
		return false;
	}
	if (pPmSerialData->length != __builtin_bswap16(sizeof(*pPmSerialData))) {
		return false;
	}

	int readChecksum_result = PMSerial.readBytes((uint8_t *)&checkSum, sizeof(checkSum));
	if (readChecksum_result != sizeof(checkSum)) {
		return false;
	}
	uint16_t calcSum
		= calcPM_checkSum((uint8_t *)&PmSerialDataMarker, sizeof(PmSerialDataMarker)) + calcPM_checkSum((uint8_t *)pPmSerialData, sizeof(*pPmSerialData));
	if (calcSum != __builtin_bswap16(checkSum)) {
		return false;
	}
	return true;
}

bool getPM_meas() {
	TPmSerialData serialData;
	uint16_t sum;
	bool readPM_result = readPM_data(&serialData);
	if (!readPM_result) {
		while (PMSerial.available() > 0) {
			char t = PMSerial.read();
		}
		PM_1_0_meas.newMeasDone = false;
		PM_2_5_meas.newMeasDone = false;
		PM_10_meas.newMeasDone = false;
		return false;
	}

	PM_1_0_meas.value += __builtin_bswap16(serialData.pm1_0); // count PM1.0 value of the air detector module
	PM_1_0_meas.measNum++;
	PM_1_0_meas.newMeasDone = true;

	PM_2_5_meas.value += __builtin_bswap16(serialData.pm2_5); // count PM2.5 value of the air detector module
	PM_2_5_meas.measNum++;
	PM_2_5_meas.newMeasDone = true;

	PM_10_meas.value += __builtin_bswap16(serialData.pm10); // count PM10 value of the air detector module
	PM_10_meas.measNum++;
	PM_10_meas.newMeasDone = true;
	return true;
}

bool getDHT11_meas() {
	// Sensor readings may also be up to 2 seconds 'old' (its a very slow sensor)
	float humid = dht.readHumidity();
	// Read temperature as Celsius (the default)
	float temp = dht.readTemperature();
	if (isnan(humid) || isnan(temp)) {
		temp_meas.newMeasDone = false;
		humid_meas.newMeasDone = false;
		return false;
	} else {
		temp_meas.measNum++;
		temp_meas.value += temp;
		temp_meas.newMeasDone = true;

		humid_meas.measNum++;
		humid_meas.value += humid;
		humid_meas.newMeasDone = true;
	}
	return true;
}

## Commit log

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2021-06-05 added assembly with tube LED, dust module and PCB
    [HAQuDA_Assembly.SLDASM, Lamp.SLDPRT, LampTubeLED.SLDASM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]
2021-06-07 added models for demo night mode and multi mode
    [DemoLed.SLDPRT, Demo_HAQuDA_Assembly_Night.SLDASM, Demo_LampTubeLed_Multi.SLDASM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]
2021-06-08 added models for shining LEDs, ESP-32, two USBs, sensors
    [DHT-11_without_case.SLDPRT, DemoLed.SLDPRT, Demo_HAQuDA_Assembly_Night.SLDASM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]
2021-06-08 added correct previews of night mode 2 without disabled LEDs
2021-06-08 added preview of multi mode and main assembly
    [HAQuDA_Assembly.SLDASM]
2021-06-08 added demo models of night mode and multi mode, main assembly, reorganized folders
    [DHT-11_without_case.SLDPRT, DemoLed.SLDPRT, Demo_HAQuDA_Assembly_Multi.SLDASM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]
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2021-06-13 added model of CCS-811 TVOC and CO2 sensor, updated all assemblies and photos of model
    [CCS811.SLDPRT, Demo_HAQuDA_Assembly_Multi.SLDASM, Demo_HAQuDA_Assembly_Night_1.SLDASM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]
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2021-06-23 added time bounds with time of day type
    [Endpoints.xlsx]
2021-06-23 added footprint of esp32 mini, added jtag on schematic
    [HaQuDA_PcbLib1.PcbLib, HaQuDA_Schlib.SchLib, Scheme.SchDoc]
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2021-06-28 started polling DHT11, TODO: fix bug with sigtrap
    [HaQuDA_PcbLib1.PcbLib, HaQuDA_Schlib.SchLib, Scheme.SchDoc]
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2021-08-16 added CCS811 on schematic, connected ZE25-O3; TODO: connect UART0 to external micro USB
    [HAQuDA_Schematic.PrjPcb, HAQuDA_board.PcbDoc, HAQuDa_schematic.SchDoc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]
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2021-08-23 fixed space between pins
    [ESP-32_mini.SLDASM]
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2021-08-23 fixed length between pins
    [ZE-25-O3_Sensor.SLDPRT]
2021-08-23 added all 3D models and pin names on top overlay
    [HAQuDA_board.PcbDoc, HAQuDa_schematic.SchDoc, HaQuDA_PcbLib.PcbLib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]
2021-08-24 added names to JTAG, ZH03B and ZE25-O3 footprints
    [HaQuDA_PcbLib.PcbLib]
2021-08-24 added RTS and DTR pins to USB-UART converter, fixed wrong size of resistors, now they are 0805
    [HAQuDA_board.PcbDoc, HAQuDa_schematic.SchDoc]
2021-08-26 fixed mistake with UART 5V logic, now VCCIO connected to 3.3V and UART drives on 3.3V logic
    [HAQuDa_schematic.SchDoc]
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2021-08-30 placed big details; TODO: start wiring and fix close location of gnd and power ports on JTAG and ZH03B footprints
    [HAQuDA_Schematic.PrjPcb, HAQuDA_board.PcbDoc, HAQuDa_schematic.SchDoc]
2021-09-01 started wiring and fix close location of gnd and power ports on JTAG and ZH03B footprints
    [HAQuDA_board.PcbDoc, HAQuDa_schematic.SchDoc, HaQuDA_PcbLib.PcbLib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]
2021-09-04 updated pcb; TODO: fix errors in DRC
    [HAQuDA_board.PcbDoc, HAQuDa_schematic.SchDoc, HaQuDA_PcbLib.PcbLib]
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2021-11-19 added height to lower body to fit 95mm tube
    [Lamp.SLDPRT]
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2021-11-20 fixed bugs with re-showing pixels every loop; adde displaying measurments with nine hours, changing brightness with blynk
    [HAQuDA_Esp32.ino]
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2021-12-06 added tasks for displaying effects, TODO: fix freezing LEDs after choosing effect
    [HAQuDA_Esp32.ino, WS2812.h]
2021-12-12 started receiving ZE25-O3 sensor's data, TODO: increase O3 concentration in air to measure it and test sensor
    [HAQuDa_schematic.SchDoc]
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2022-01-05 added multi-mode and total parameter, fixed bug with unreadable brightness in calculating RGB of parameters
    [HAQuDA_Esp32.ino, Sensors.cpp, WS2812.h]
2022-01-06 renamed meas structs for PM, added clearing UART Rx buffer of ZH03B and ZE25-O3 in case of wrong data
    [Sensors.cpp]
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2022-01-07 fixed wrong new line symbols in Blynk logging, problem was caused by terminal buffer length
    [HAQuDA_Esp32.ino]
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2022-01-23 added polygons for each pad and via to them for better cooling
    [HAQuDA_Schematic.PrjPcb, HAQuDa_schematic.SchDoc, HaQuDA_PcbLib.PcbLib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]
2022-01-23 added 5V and SPARE pins for touch sensor on future upper PCB
    [PcbLib.PcbLib, Schlib.SchLib, WS2812_PCB_stack.PcbDoc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]
2022-01-23 added bare ESP32-WROOM32 module, initial placement of WS2812 PCBs pads
    [HAQuDA_board.PcbDoc, HAQuDa_schematic.SchDoc, HaQuDA_PcbLib.PcbLib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]
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2022-01-24 added footprints for WS2812 PCB stacks and finished placement of other main components
    [HAQuDA_board.PcbDoc, HAQuDa_schematic.SchDoc, HaQuDA_PcbLib.PcbLib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]
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2022-01-26 fixed body, lamp upper size (it narrow to the top), added stiffeners and fasteners for M2 screw
    [IlyaOrazov.STL, Lamp.SLDPRT]
2022-01-26 fixed radius of WS2812 PCB stacks circle on the lower and upper PCBs because of narrow to the top of lamp diffuser
    [HAQuDA_board.PcbDoc, HAQuDA_upper_PCB.PcbDoc, WS2812_PCB_stack.PcbDoc]
2022-01-27 fixed wrong upper side of body, increased size of ventilation grid, height of fasteners and stiffeners are now right in relation to PCB position and USB connectors holes
    [Lamp.SLDPRT]
2022-01-27 increased radius of WS2812 PCB stacks positions to 36mm, finished routing; TODO: add touch panels on PCB
    [HAQuDA_upper_PCB.PcbDoc, HAQuDA_upper_PCB.PrjPcb, HAQuDA_upper_PCB_schematic.SchDoc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]
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2022-01-27 WS2812 PCB stacks are now in right positions
    [HAQuDA_board.PcbDoc]
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2022-01-31 fixed wrong position of WS2812 stacks
    [HAQuDA_upper_PCB.PcbDoc]
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2022-02-01 updated WS2812 PCB stack footprint: increased hole size to fit with whole stack
    [HAQuDA_Upper_PCB.PcbLib, HAQuDA_Upper_PCB.SchLib, HAQuDA_upper_PCB.PcbDoc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]
2022-02-01 redesign PCB stack outline to fit 8 stacks in 100x100mm JLC panel
    [WS2812_PCB_stack.PcbDoc]
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2022-02-02 increased WS2812 PCB stack size to fit in cap height and added cutout to easier mount
    [1.SLDASM, 1.SLDPRT, 10.SLDPRT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]
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2022-02-02 added vias to gnd pads of WS2812 connectors for better fastening reliability
    [HAQuDA_Upper_PCB.PcbLib, HAQuDA_board.PcbDoc, HAQuDA_upper_PCB.PcbDoc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]
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2022-02-13 changed PCB panel for WS2812 stacks, for fit in 100x100mm panel, increased width of each stack to process v-cut
    [WS2812_PCB_stack.PcbDoc, WS2812_PCB_stack.PrjPcb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]
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2022-03-07 created separated model of case and changed some sizes according to real assembly
    [Ilya_4.STL, Lamp.SLDPRT, Lamp_case.SLDPRT]
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2022-03-09 decreased last upper wall thickness to 2mm and added chamfer to usb micro notch
    [HAQuDA_Assembly.SLDASM, Lamp_case.SLDPRT]
2022-03-19 fixed errors in schematic
    [HAQuDA_upper_PCB.PcbDoc, HAQuDa_schematic.SchDoc, WS2812_PCB_stack.PrjPcb]
2022-03-19 fix incorrect wifi startup during initialization processes
    [HAQuDA_Esp32.ino]
2022-03-19 change objects creating method for fix "assertion "Invalid mbox" failed:"
    [HAQuDA_Esp32.ino]
2022-03-19 WIP. temporary fix for network exception when Wi-Fi is not ready
    [HAQuDA_Esp32.ino]
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2022-05-09 fixed wrong pin connections in schematic and pcb on main board, changed rectangular slots for WS2812 stacks to rounded rectangular
    [HAQuDA_Schematic.PrjPcb, HAQuDA_board.PcbDoc, HAQuDa_schematic.SchDoc]
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2022-05-15 rework serial deiver for PM sensor
    [Sensors.cpp]
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2022-06-13 fixed bug with off white columns in night mod, when brightness < 22%
    This bug occurs when whiteBrightness * pixels.getBrightness / 255 < 2 because of Adafruit NeoPixel library's internal algorithms of fast converting LED colors
    [HAQuDA_Esp32.ino, WS2812.h]
2022-07-29 fixed bug when sensor NaN value not handling by getRGB method
2022-07-29 fixed bug with first display without measurments
    [HAQuDA_Esp32.ino]
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2022-07-29 fixedd bug when after changing Snake effect to some meas displaty mode, Snake still moving and changing some LEDs color
    [HAQuDA_Esp32.ino]
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2022-08-14 fixed errors: wrong WS2812 panels footprint position, small polygons gap, big holes for panels
    [HAQuDA_Upper_PCB.PcbLib, HAQuDA_upper_PCB.PcbDoc, HAQuDA_upper_PCB_schematic.SchDoc]
2022-08-14 updated upper PCB, TODO: add touch sensors after checking their work on prepared PCBs
    [HAQuDA_upper_PCB.PrjPcb]
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2022-08-14 replaced polygons with two pads same shape, reduced size of holes
    [HaQuDA_PcbLib.PcbLib]
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2022-08-15 replaced some SENSOR pins for better routing
    [HAQuDa_schematic.SchDoc]
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2022-08-15 made minor corrections
    [HAQuDA_upper_PCB.PcbDoc, HAQuDA_upper_PCB.PrjPcb]
2022-08-15 fixed wrong position of WS2812 stacks footprints; made minor corrections
    [HAQuDA_Schematic.PrjPcb, HAQuDA_board.PcbDoc]
2022-08-19 added TTP223 IC on scheme for using with 4 touch pads, created TTP223 and touch pad footprints
    [HAQuDA_Upper_PCB.PcbLib, HAQuDA_Upper_PCB.SchLib, HAQuDA_upper_PCB.PcbDoc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]
2022-08-19 changed connector footprint: decreased size of pads, increased gap between GND pads and signal pads, increased GND polygon gap, for better assembly
    [PcbLib.PcbLib, Schlib.SchLib, WS2812_PCB_stack.PcbDoc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]
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2022-08-19 changed WS2812 PCB panel footprint according to changes of WS2812 panel, placed components
    [HAQuDA_Upper_PCB.PcbLib, HAQuDA_upper_PCB.PcbDoc, HAQuDA_upper_PCB.PrjPcb]
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2022-08-20 added keep-out regions around touch pads for less capacitance, added WS2812 connectors designators on top overlay
    [HAQuDA_Upper_PCB.PcbLib, HAQuDA_upper_PCB.PcbDoc, HAQuDA_upper_PCB.PrjPcb]
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2022-08-20 changed keep-out regions for better routing, made vias in pads without solder mask expansion
    [HAQuDA_Upper_PCB.PcbLib, HAQuDA_upper_PCB.PcbDoc, HAQuDA_upper_PCB.PrjPcb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]
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2022-08-21 changed CCS811_WAK pin from GPIO5 to GPIO25, because GPIO5 has internal pull-up
    [HAQuDA_Schematic.PrjPcb, HAQuDA_board.PcbDoc, HAQuDa_schematic.SchDoc]
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2022-08-21 updated Panel, deleted board shape in Mechanical 1, because we only need milling cutter on outer shape and V-cut between stacks
    [WS2812_PCB_stack_Panel_100x100.PcbDoc]
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2022-08-25 fixed via sizes: made annular ring >= 0.2mm according to factory capabilities
    [HAQuDA_Schematic.PrjPcb, HAQuDA_Upper_PCB.PcbLib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]
2022-08-28 replaced 100x100mm panel with 9pcs. panel because it's price is more profitable
    [WS2812_PCB_stack.PrjPcb, WS2812_PCB_stack_Panel_100x100.PcbDoc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]
2022-08-28 fixed waste vias for +5V, replaced capacitors on input power lines for better connection
    [HAQuDA_board.GBL, HAQuDA_board.GBO, HAQuDA_board.GBP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]
2022-08-28 fixed error with solder mask expansion aroung slots for WS2812 PCB stack
    [HAQuDA_Schematic.PrjPcb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]
2022-08-28 replaced silkscreen on bottom layer around WS2812 PCB stack slots for better visibility
    [HAQuDA_upper_PCB.PcbDoc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]
2022-08-28 fixed error with wrong position of GND poly on top layer
    [HAQuDA_upper_PCB.PcbDoc, HAQuDA_upper_PCB.PrjPcb]
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2022-09-19 fixed mixed up 5V and IO texts for 2nd WS2812 PCB panel
    [HAQuDA_Schematic.PrjPcb, HAQuDA_board.PcbDoc]
